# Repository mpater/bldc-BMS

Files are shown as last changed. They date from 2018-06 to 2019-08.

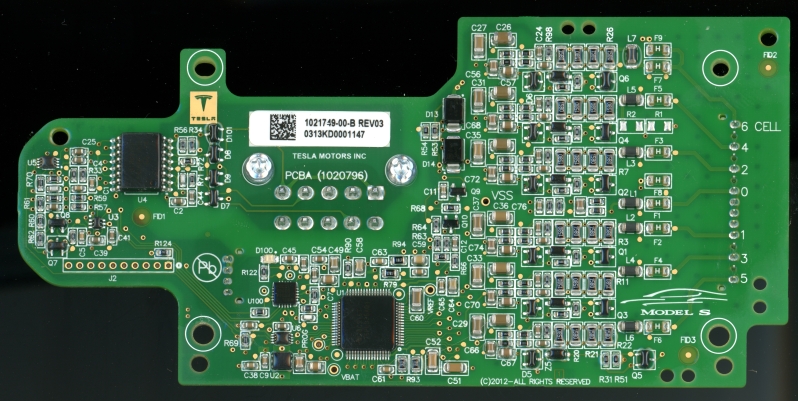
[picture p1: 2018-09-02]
datasheets/Telsa BMS.jpg

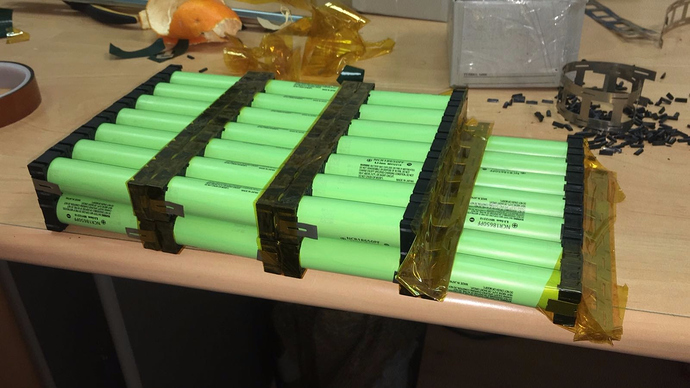
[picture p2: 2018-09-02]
datasheets/d7e37abb86a020a3c7433f02802cd9611f8715d7_1_690x388.jpg

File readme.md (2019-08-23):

# VESC BMS
## Overview
Battery Managment System (BMS) for (but not limited to) an Electronic Speed Controller, specifically for a longboard controller (VESC). 

Current battery pack specifications are LiFePO4 (3.2V nominal, ~2.6Ah) in a 6s2p, giving 19.2V with 5Ah (96Wh). Continuous discharge is about 20A (384W) with 30 second pulse discharge of 52A (1kW) and charge current of 5.2A (21.9V), for a 2p configuration.

Scope of the project is to design a BMS to meet the above specifications using off-the-shelf ICs for the battery managment section. A microcontroller circuit would also be incorperated to allow communication between the BMS and controller (SMBus/I2C), contrller and PC (USB-serial) and contrller and VESC (CAN bus).

Texis Instruments (TI) appears to have the most comprehensive set of battery managment systems offerings. These appear to be split up into two main sections: cell monitors and gas gauges. 
The bq769x0 seires will be used for the cell monitoring, offering bq76920, bq76930 and bq76940 based on the pack size. 
Currently the top candidats for the gas gauge are bq78350-R1 and bq34z100-R1 but more research is needed to determine which one is better suited. 

## BMS
- **Cell Monitor**
  - Measure cell voltages and pack current (Coulomb Counter)
  - Cell and temperature measurment
  - Charge Limit (over-voltage and over-amperage)
  - Discharge Limit (under-Voltage and over-amperage)
  - Balancing circuitry and autobalancing mode
  - 
- **'Gas Gauge' and Battery Managment Controller**
  - Estimate pack State of Charge (SoC)
  - Estimate pack State of Health (SoH)
  - Estimate time-to-empty
  - Lifetime datalogging
  - Aging compensation (optional)
  - Self-discharge compensation (optional)

### Cell Monitor
**bq76930**
- 6-19 cells, various chemistries
- 0x08 I2C Address (7-bit), 2.5V LDO, No CRC, 30-TSSOP (PW)
- PN bq7693000DBT

### Gas Gauge

#### bq78350-R1 - Gas Gauge via CEDV
See Technical Reference Sections:
- 9.1.11 - EDV Age Fator - Compensate for cell aging
- 9.1.12 - Self Discharge - estimate self-discharge

#### bq34z100-R1 - Gas Gauge via Impedance Track
'Impedance Track' module from TI give aging compensation and self-discharge compensation -> not true, bq78350 also has this. 
This module does not interface with cell monitor and reads only pack volage, how does it konw self-discharge issues?

## Microcontroller
The MCU provides a communiciton bridge between the gas gauge and PC (serial via USB) and gas gauge and VESC (CAN bus). The MCU does not need to be powered when either of these functions are not used, thus power to operate the MCU should come from either one of these communiciton ports. 
(or have MCU sleep when USB-serial timeout or CAN timeout? Wake-up via interrupt on button or USB-serial or CAN? Seems complicated.)

Firware updates done via SWD or Device firmware update via [USB DFU](http://www.st.com/content/ccc/resource/technical/document/application_note/6a/17/92/02/58/98/45/0c/CD00264379.pdf/files/CD00264379.pdf/jcr:content/translations/en.CD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).

STM32F072C8T6TR
CAN, HDMI-CEC, I²C (SMBus), IrDA, LIN, SPI, UART/USART, USB
IC MCU 32BIT 64KB FLASH 48LQFP
ARM® Cortex®-M0 STM32F0 Microcontroller IC 32-Bit 48MHz 64KB (64K x 8) FLASH 48-LQFP (7x7)

## Reference Projects
- TI Reference Design - TIDA-00449
- TI Reference Design - TIDA-00792
- TI Reference Disign - TIDA-00255
- LibreSolar
  - Also using bq769x0 for cell monitor but no gas gauge, that function is done by the MCU (STM32F072)

## TODO
- [x] Determine pack size and output - see intro
- [x] Determine cell monitor - bq76930
- [x] Determine gas gauge - bq78350-R1 or bq34z100-R1
- [x] Determine MCU - STM32F072 (USB-to-serial, USB bootloader, I2C, CAN)
- [x] 100% - Schematic capture
   - [x] Add pre-charge circuit
   - [x] Change balancing circuit from PNP to NPN
   - [x] Change power-stange layout to POS rail on top of sheet
   - [x] Setup for 6s? or have populated bypass for this layout
   - [x] Press button to show SoC LED display with gas-gauge?
   - [x] Jumper for MCU to be powered by pack
- [x] 100% - BoM and footprint selection for PCB
- [x] 1000% - Determine PCB footprint size constraights (multiple of 26650 cell size)
- [x] 100% - PCB capture
- [ ] 0% - write driver for gas gauge on MCU
- [ ] 0% - write interface module for MCU to PC
- [x] 100% - Order PCB and components
- [x] 100% - Assemble components on PCB
- [x] 100% - Hardware validation testing
- [ ] TI SMBus to PC moudule is very expensive, looking for something similar to view BMS status

## PCB_2019-06 TOFIX
- [ ] Swap I2C's on STM32F0 as I2C1 only support SMBus for bq78350-r1
- [ ] Mirror STM32F0 debug conn pinout
- [ ] Assemble and test PCB

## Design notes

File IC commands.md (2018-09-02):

## bq78350-R1
- ManufacturerAccess
- RemainingCapacityAlarm
- RemainingTimeAlarm
- BatteryMode
- BatteryMode
- AtRate
- AtRateTimeToFull
- AtRateTimeToEmpty
- AtRateOK
- Temperature
- Voltage
- Current
- AverageCurrent
- MaxError
- RelativeStateOfCharge
- AbsoluteStateOfCharge
- RemainingCapacity
- FullChargeCapacity
- RunTimeToEmpty
- AverageTimeToEmpty
- AverageTimeToFull
- ChargingCurrent
- ChargingVoltage
- BatteryStatus
- CycleCount
- DesignCapacity
- DesignVoltage
- SpecificationInfo
- ManufacturerDate
- SerialNumber
- ManufacturerName
- DeviceName
- DeviceChemistry
- ManufacturerData
- HostFETControl
- GPIOStatus
- GPIOControl
- VAUXVoltage
- Authenticate
- CellVoltage15 ... CellVoltage1
- DynamicPower
- ExtAveCellVoltage
- PendingEDV
- StateOfHealth
- SafetyAlert
- SafetyStatus
- PFAlert
- PFStatus
- OperationStatus
- ChargingStatus
- GaugingStatus
- ManufacturingStatus
- AFEStatus
- AFEConfig
- AFEVCx
- AFEData
- Lifetime Data Block 1 ... Lifetime Data Block 7
- ManufacturerInfo
- DAStatus 1
- DAStatus 2
- CUV Snapshot
- COV Snapshot

## bq34z100-G1
- Control()
- StateOfCharge()
- MaxError()
- RemainingCapacity()
- FullChargeCapacity()
- Voltage()
- AverageCurrent()
- Temperature()
- Flags()
- Current()
- FlagsB()

Extended Commands
- AverageTimeToEmpty()
- AverageTimeToFull()
- PassedCharge()
- DoD0Time()
- AvailableEnergy()
- AveragePower()
- Serial Number
- Internal_Temperature()
- CycleCount() - number of cycles the battery has
experienced
- StateOfHealth() - the ratio of predicted FCC (25°C, SOH current rate) over the DesignCapacity()
- ChargeVoltage() - recommended charging voltage output from the JEITA charging profile
- ChargeCurrent() - recommended charging current output from the JEITA charging profile
- PackConfiguration()
- DesignCapacity()
- DataFlashClass() (2)
- DataFlashBlock() (2)
- Authenticate()/BlockData()
- AuthenticateCheckSum()/BlockData()
- BlockData()
- BlockDataCheckSum()
- BlockDataControl()
- GridNumber()
- LearnedStatus()
- DoD@EoC() - depth of discharge (DOD) at the end of charge
- QStart() - initial capacity calculated from IT simulation
- TrueRC() - True remaining capacity from IT simulation
- TrueFCC() - True full charge capacity from IT simulation
- StateTime() - time past since last state change (DISCHARGE, CHARGE, REST)
- QMaxPassedQ
- DOD0()
- QmaxDOD0()
- QmaxTime()

## bq76930
- SYS_STAT
- CELLBAL1 CELLBAL2 - Enable individual cells for balancing
- SYS_CTRL1
- SYS_CTRL2 - Discharge and Charge FET control
- PROTECT1
- PROTECT2
- PROTECT3
- OV_TRIP
- UV_TRIP
- CC_CFG
- VC1_HI VC1_LO
- BAT_HI BAT_LO
- TS1_HI TS1_LO
- TS2_HI TS2_LO
- CC_HI CC_LO
- ADCGAIN1
- ADCOFFSET
- ADCGAIN2

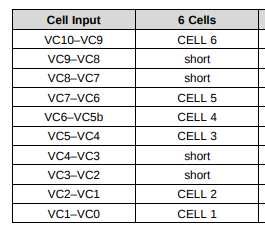
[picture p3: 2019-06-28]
datasheets/6-cell-config.png

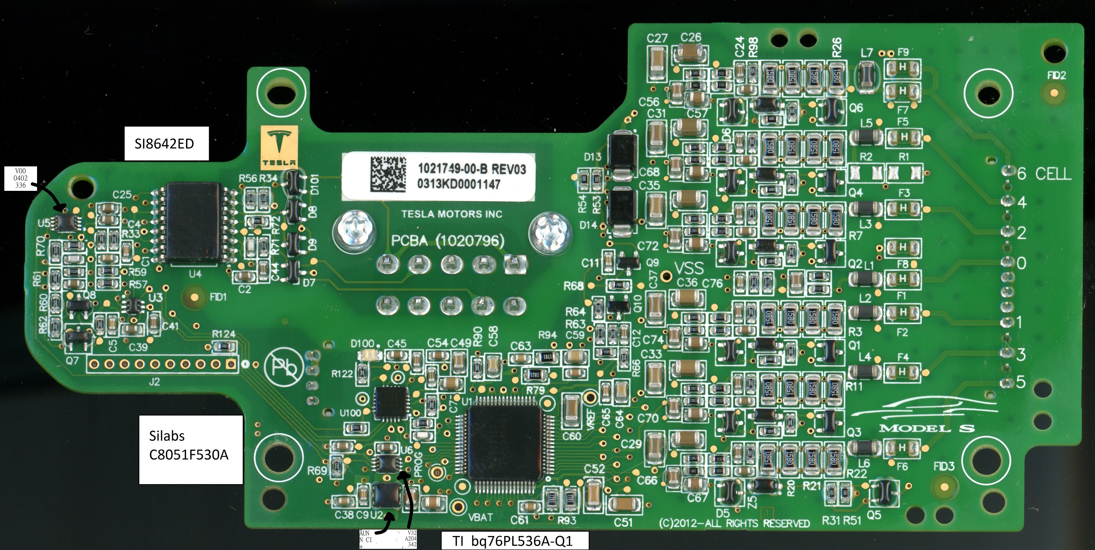
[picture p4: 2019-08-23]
datasheets/Telsa BMS large.jpg

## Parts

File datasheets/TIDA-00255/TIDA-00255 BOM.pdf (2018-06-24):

TI DESIGNS TIDA00255-bq76940

Item | Qty | Reference | Value | Part Description | Manufacturer | Manufacturer Part Number | Alternate Part | PCB Footprint | Note
1 | 6 | C1, C2, C3, C40, C41, C42 | 0.1uF | CAP, CERM, 0.1uF, 50V, +10/%, | MuRata | GCM188R71H104KA57B | | 0603 | -
2 | 4 | C4, C5, C6, C7 | 0.1uF | CAP, CERM, 0.1uF, 100V, +/-10%, X7R, 0603 | MuRata | GRM188R72A104KA35D | | 0603
3 | 21 | C8, C9, C10, C11, C12, C13, C14, C15, C16, C17, C18, C19, C21, C22, C23, C28, C29, C30, C31, C32, C33 | 1uF | CAP, CERM, 1uF, 16V, +10/%, X7R, 0805 | MuRata | GRM21BR71C105KA01L | | 0805
4 | 3 | C24, C25, C26 | 4700pF | CAP, CERM, 4700pF, 50V, +/-10%, X7R, 0805 | AVX | 08055C472KAT2A | | 0805
5 | 1 | C27 | 4.7uF | CAP, CERM, 4.7uF, 10V, +10/%, X7R, 0805 | MuRata | GRM21BR71A475KA73L | | 0805
6 | 3 | C34, C35, C36 | 10uF | CAP, CERM, 10uF, 35V, +/-10%, X7R, 1210 | MuRata | GRM32ER7YA106KA12L | | 1210
7 | 1 | C37 | 1uF | CAP, CERM, 1uF, 50V, +/-10%, X7R, 1206 | MuRata | GRM31MR71H105KA88L | | 1206
8 | 1 | C39 | 3300pF | CAP, CERM, 3300pF, 25V, +/-10%, X7R, 0603 | MuRata | GRM188R71E332KA01D | | 0603
9 | 1 | D1 | 75V | Diode, TVS, Uni, 75V, 1500W, SMC | Fairchild Semiconducto SMCJ75A | | | SMC
10 | 6 | D2, D22, D23, D24, D41, D46 100V | | Diode, Ultrafast, 100V, 0.15A, SOD-123 | Diodes Inc. | 1N4148W-7-F | | SOD-123
11 | 3 | D3, D45, D47 | 16V | Diode, Zener, 16V, 500mW, SOD-123 | Diodes Inc. | MMSZ5246B-7-F | | SOD-123
12 | 1 | D4 | 600V | Diode, Ultrafast, 600V, 3A, SMC | ON Semiconductor | MURS360T3G | | SMC
13 | 21 | D6, D7, D8, D9, D10, D11, D1 5.6V | | Diode, Zener, 5.6V, 200mW, SOD-323 | Diodes Inc. | MMSZ5232BS-7-F | | SOD-323
14 | 5 | D48, D49, D50, D51, D52 | Green | LED, Green, SMD | Lite-On | LTST-C190GKT | | 1.6x0.8x0.8mm
15 | 1 | D55 | Orange | LED, Orange, SMD | Lite-On | LTST-C190KFKT | | 1.6x0.8x0.8mm
16 | 1 | D56 | 6.8V | Diode, Zener, 6.8V, 500mW, SOD-123 | Diodes Inc. | MMSZ5235B-7-F | | SOD-123
17 | 3 | FID1, FID2, FID3 | | Fiducial mark. There is nothing to buy or mount. | N/A | N/A | | Fiducial
18 | 4 | H1, H2, H3, H4 | | Bumpon, Hemisphere, 0.375 X 0.235, Black | 3M | SJ61A2 | | Black Bumpon
19 | 4 | J1, J2, J3, J4 | | TERMINAL SCREW PC 30AMP, TH | Keystone | 8199 | | 12.9x6.3x7.9 mm
20 | 1 | J5 | | Header, 3.5mm, 11POS, R/A, TH | Molex | 395021011 | | 39.90x7.03x9.33 mm
21 | 4 | J6, J7, J11, J12 | | Header, 100mil, 2x1, Tin plated, TH Sullins Connector Solut PEC02SAAN | | | | Header, 2 PIN, 100mil, Tin
22 | 2 | J8, J17 | | Header, 100mil, 4x1, R/A, TH | Molex | 22-05-3041 | | 4x1 R/A Header
23 | 1 | J9 | | Header, 3.5mm, 5POS, R/A, TH | Molex | 395021005 | | 19.03x7.03x9.33 mm

# Bill of Materials

Item | Qty | Reference | Value | Part Description | Manufacturer | Manufacturer Part Number | Alternate Part | PCB Footprint | Note
24 | 1 | J14 | | Header, 100mil, 5x2, Tin plated, TH Sullins Connector Solut PEC05DAAN | | | | Header, 5x2, 100mil, Tin
25 | 1 | J15 | | Header, 100mil, 3x2, Tin, TH | Sullins Connector Solut PEC03DAAN | | | 3x2 Header
26 | 1 | J16 | | Header, 100mil, 3x1, Tin plated, TH Sullins Connector Solut PEC03SAAN | | | | Header, 3 PIN, 100mil, Tin
27 | 1 | LBL1 | | Thermal Transfer Printable Labels, | Brady | THT-14-423-10 | - | PCB Label 0.650"H x 0.200"W
28 | 1 | P1 | | CONN TERM BLOCK 3.5MM 11POS | Molex Connector Corpo39500-0011 | | 1840450 | Term Block Plug
29 | 1 | P2 | | CONN TERM BLOCK 3.5MM 5POS | Molex Connector Corpo39500-0005 | | - | Term Block Plug
30 | 2 | Q2, Q4 | 100V | MOSFET, N-CH, 100V, 18A, DDPAK | AOS | AOB290L | | DDPAK
31 | 2 | Q5, Q15 | -100V | MOSFET, P-CH, -100V, -0.6A, SOT- | Diodes Inc. | ZXMP10A13FTA | | SOT-23
32 | 8 | Q6, Q7, Q8, Q9, Q10, Q11, Q 20V | | MOSFET, P-CH, 20V, 0.83A, | Fairchild Semiconducto FDY1002PZ
33 | 2 | Q14, Q22 | 100V | MOSFET, N-CH, 100V, 0.19A, SOT- | NXP Semiconductor | BST82,215 | | SOT-23
34 | 2 | Q16, Q17 | 100V | MOSFET, N-CH, 100V, 0.17A, SOT- | Fairchild Semiconducto BSS123 | | | SOT-23
35 | 1 | Q18 | 0.5V | Transistor, PNP, 300V, 0.2A, SOT- | Fairchild Semiconducto MMBTA92 | | None | SOT-23
36 | 1 | Q19 | 50V | MOSFET, N-CH, 50V, 0.22A, SOT- | Fairchild Semiconducto BSS138 | | | SOT-23
37 | 1 | Q20 | 0.21V | Transistor, NPN, 20V, 5.25A, SOT- | Diodes Inc. | ZXTN19100CZTA | | SOT-89
38 | 18 | R2, R4, R44, R45, R46, R47, R 100 | | RES, 100 ohm, 1%, 0.125W, 0805 | Vishay-Dale | CRCW0805100RFKEA | | 0805
39 | 1 | R3 | 0.001 | RES, 0.001 ohm, 1%, 2W, 4527 | Vishay-Dale | WSR21L000FEA | | 4527
40 | 7 | R5, R8, R9, R104, R111, R116 1.00Meg | | RES, 1.00Meg ohm, 1%, 0.125W, | Vishay-Dale | CRCW08051M00FKEA | | 0805
41 | 2 | R6, R87 | 0 | RES, 0 ohm, 5%, 0.125W, 0805 | Vishay-Dale | CRCW08050000Z0EA | | 0805
42 | 22 | R7, R20, R21, R22, R23, R24, | 1.00k | RES, 1.00k ohm, 1%, 0.125W, 0805 | Vishay-Dale | CRCW08051K00FKEA | | 0805
43 | 15 | R10, R11, R12, R13, R14, R15 100 | | RES, 100 ohm, 1%, 0.25W, 1206 | Vishay-Dale | CRCW1206100RFKEA | | 1206
44 | 19 | R32, R33, R34, R35, R36, R37 10.0k | | RES, 10.0k ohm, 1%, 0.125W, 0805 | Vishay-Dale | CRCW080510K0FKEA | | 0805
45 | 1 | R42 | 499k | RES, 499k ohm, 1%, 0.125W, 0805 | Vishay-Dale | CRCW0805499KFKEA | | 0805
46 | 1 | R43 | 3.01k | RES, 3.01k ohm, 1%, 0.125W, 0805 | Vishay-Dale | CRCW08053K01FKEA | | 0805
47 | 6 | R75, R78, R101, R103, R107, | 100k | RES, 100k ohm, 1%, 0.125W, 0805 | Vishay-Dale | CRCW0805100KFKEA | | 0805
48 | 16 | R76, R124, R125, R126, R127 200 | | RES, 200 ohm, 1%, 0.125W, 0805 | Vishay-Dale | CRCW0805200RFKEA | | 0805
49 | 1 | R85 | 0 | RES, 0 ohm, 5%, 0.25W, 1206 | Vishay-Dale | CRCW12060000Z0EA | | 1206
50 | 1 | R94 | 300k | RES, 300k ohm, 0.1%, 0.1W, 0603 | Susumu Co Ltd | RG1608P-304-B-T5 | | 0603
51 | 2 | R95, R97 | 100k | RES, 100k ohm, 0.1%, 0.1W, 0603 | Susumu Co Ltd | RG1608P-104-B-T5 | | 0603
52 | 2 | R96, R102 | 7.68k | RES, 7.68k ohm, 0.1%, 0.1W, 0603 | Susumu Co Ltd | RG1608P-7681-B-T5 | | 0603
53 | 1 | R105 | 5.6k | RES, 5.6k ohm, 5%, 1W, 2512 | Panasonic | ERJ-1TYJ562U | | 2512
54 | 1 | R106 | 196k | RES, 196k ohm, 1%, 0.125W, 0805 | Vishay-Dale | CRCW0805196KFKEA | | 0805
55 | 2 | R110, R122 | 49.9k | RES, 49.9k ohm, 1%, 0.125W, 0805 | Vishay-Dale | CRCW080549K9FKEA | | 0805
56 | 1 | R120 | 221k | RES, 221k ohm, 1%, 0.125W, 0805 | Vishay-Dale | CRCW0805221KFKEA | | 0805
57 | 1 | R121 | 698 | RES, 698 ohm, 1%, 0.125W, 0805 | Vishay-Dale | CRCW0805698RFKEA | | 0805
58 | 3 | RT1, RT2, RT3 | 10.0k ohm | Thermistor NTC, 10.0k ohm, 1%, | SEMITEC Corporation | 103AT-2 | | Disc, 5x8.4 mm
59 | 2 | S1, S2 | | Switch, Tactile, SPST-NO, 0.05A, | TE Connectivity | 4-1437565-1 | | SW, SPST 6x6 mm
60 | 1 | S3 | | Switch, SPST 9Pos, Rocker, TH | Grayhill | 76SB09ST | | 9.65X8X24.9mm
61 | 1 | S4 | | Switch, SPST 8Pos, Rocker, TH | Grayhill | 76SB08ST | | 9.65X8X22.4mm
62 | 10 | SH-J6, SH-J7, SH-J11, SH-J12, 1x2 | | Shunt, 100mil, Gold plated, Black | 3M | 969102-0000-DA | SNT-100-BK-G | Shunt
63 | 4 | TP3, TP4, TP5, TP6 | Black | Test Point, TH, Multipurpose, Black Keystone | | 5011 | | Keystone5011
64 | 3 | TP48, TP49, TP50 | Yellow | Test Point, Multipurpose, Yellow, | Keystone | 5014 | | Yellow Multipurpose Testpoint
65 | 1 | U1 | | bq76940 AFE for 15-Series Cell | Texas Instruments | BQ7694000DBT | | DBT0044A
66 | 1 | U2 | | Companion Controller for bq769x0 | Texas Instruments | BQ78350DBT | | DBT0030A
67 | 0 | C20 | 470pF | CAP, CERM, 470pF, 50V, +/-10%, | AVX | 08055C471KAT2A | | 0805
68 | 0 | C38 | 3300pF | CAP, CERM, 3300pF, 25V, +/-10%, | MuRata | GRM188R71E332KA01D | | 0603
69 | 0 | D5 | 600V | Diode, Ultrafast, 600V, 8A, TH | ON Semiconductor | MUR860G | | TO-220AC
70 | 0 | D16, D17, D18, D19, D20, D2 0.8V | | Diode, Schottky, 30V, 0.2A, SOD- | ON Semiconductor | BAT54T1G | | SOD-123
71 | 0 | D37 | | Diode, Schottky, 30V, 0.2A, SOD- | ON Semiconductor | BAT54T1G | | SOD-123
72 | 0 | D38, D39, D40, D42 | | Diode, TVS, Uni, 30V, 600W, SMB | Diodes Inc. | SMBJ30A-13-F | | SMB
73 | 0 | HS1, HS2, HS3, HS4 | | Heatsink, DDPAK/TO-263, SMT | Aavid | 573300D00010G | | Heatsink, DDPAk

Item | Qty | Reference | Value | Part Description | Manufacturer | Manufacturer Part Number | Alternate Part | PCB Footprint | Note
74 | 0 | J10 | | Header, TH, 100mil, 3x1, Gold | Samtec, Inc. | TSW-103-07-G-S | | TSW-103-07-G-S
75 | 0 | J13 | | Header, TH, 100mil, 7x1, Gold | Samtec | TSW-107-07-G-S | | 7x1 Header
76 | 0 | J18, J19 | | Header, TH, 100mil, 5x1, Gold | Samtec, Inc. | TSW-105-07-G-S | | TSW-105-07-G-S
77 | 0 | J20 | | Header, TH, 100mil, 6x1, Gold | Samtec, Inc. | TSW-106-07-G-S | | TSW-106-07-G-S
78 | 0 | Q1, Q3 | 100V | MOSFET, N-CH, 100V, 18A, DDPAK | AOS | AOB290L | | DDPAK
79 | 0 | Q21 | 0.7V | Transistor, NPN, 65V, 0.1A, SOT-23 | ON Semiconductor | BC846BLT1G | None | SOT-23
80 | 0 | R1, R50, R51, R123 | 0 | RES, 0 ohm, 5%, 0.125W, 0805 | Vishay-Dale | CRCW08050000Z0EA | | 0805
81 | 0 | R74 | 100k | RES, 100k ohm, 1%, 0.125W, 0805 | Vishay-Dale | CRCW0805100KFKEA | | 0805
82 | 0 | R77 | 200 | RES, 200 ohm, 1%, 0.125W, 0805 | Vishay-Dale | CRCW0805200RFKEA | | 0805
83 | 0 | R80, R81, R98, R99, R113 | 1.00k | RES, 1.00k ohm, 1%, 0.125W, 0805 | Vishay-Dale | CRCW08051K00FKEA | | 0805
84 | 0 | R84 | 300k | RES, 300k ohm, 0.1%, 0.1W, 0603 | Susumu Co Ltd | RG1608P-304-B-T5 | | 0603
85 | 0 | R86 | 0 | RES, 0 ohm, 5%, 0.25W, 1206 | Vishay-Dale | CRCW12060000Z0EA | | 1206
86 | 0 | R88, R93 | 100k | RES, 100k ohm, 0.1%, 0.1W, 0603 | Susumu Co Ltd | RG1608P-104-B-T5 | | 0603
87 | 0 | R91, R92, R100 | 1.00Meg | RES, 1.00Meg ohm, 1%, 0.125W, | Vishay-Dale | CRCW08051M00FKEA | | 0805
88 | 0 | TP1 | Black | Test Point, TH, Multipurpose, Black Keystone | | 5011 | | Keystone5011
89 | 0 | TP2, TP14 | Red | Test Point, TH, Multipurpose, Red | Keystone | 5010 | | Keystone5010
90 | 0 | TP7, TP8, TP10, TP11, TP13, T White | | Test Point, TH, Multipurpose, | Keystone | 5012 | | Keystone5012

IMPORTANT NOTICE FOR TI REFERENCE DESIGNS Texas Instruments Incorporated ("TI") reference designs are solely intended to assist designers (“Buyers”) who are developing systems that incorporate TI semiconductor products (also referred to herein as “components”). Buyer understands and agrees that Buyer remains responsible for using its independent analysis, evaluation and judgment in designing Buyer’s systems and products.
TI reference designs have been created using standard laboratory conditions and engineering practices. TI has not conducted any
testing other than that specifically described in the published documentation for a particular reference design. TI may make
corrections, enhancements, improvements and other changes to its reference designs.
Buyers are authorized to use TI reference designs with the TI component(s) identified in each particular reference design and to modify the reference design in the development of their end products. HOWEVER, NO OTHER LICENSE, EXPRESS OR IMPLIED, BY ESTOPPEL OR OTHERWISE TO ANY OTHER TI INTELLECTUAL PROPERTY RIGHT, AND NO LICENSE TO ANY THIRD PARTY TECHNOLOGY OR INTELLECTUAL PROPERTY RIGHT, IS GRANTED HEREIN, including but not limited to any patent right, copyright, mask work right, or other intellectual property right relating to any combination, machine, or process in which TI components or services are used. Information published by TI regarding third-party products or services does not constitute a license to use such products or services, or a warranty or endorsement thereof. Use of such information may require a license from a third party under the patents or other intellectual property of the third party, or a license from TI under the patents or other intellectual property of TI.
TI REFERENCE DESIGNS ARE PROVIDED "AS IS". TI MAKES NO WARRANTIES OR REPRESENTATIONS WITH REGARD TO THE REFERENCE DESIGNS OR USE OF THE REFERENCE DESIGNS, EXPRESS, IMPLIED OR STATUTORY, INCLUDING ACCURACY OR COMPLETENESS. TI DISCLAIMS ANY WARRANTY OF TITLE AND ANY IMPLIED WARRANTIES OF MERCHANTABILITY, FITNESS FOR A PARTICULAR PURPOSE, QUIET ENJOYMENT, QUIET POSSESSION, AND NON-INFRINGEMENT OF ANY THIRD PARTY INTELLECTUAL PROPERTY RIGHTS WITH REGARD TO TI REFERENCE DESIGNS OR USE THEREOF. TI SHALL NOT BE LIABLE FOR AND SHALL NOT DEFEND OR INDEMNIFY BUYERS AGAINST ANY THIRD PARTY INFRINGEMENT CLAIM THAT RELATES TO OR IS BASED ON A COMBINATION OF COMPONENTS PROVIDED IN A TI REFERENCE DESIGN. IN NO EVENT SHALL TI BE LIABLE FOR ANY ACTUAL, SPECIAL, INCIDENTAL, CONSEQUENTIAL OR INDIRECT DAMAGES, HOWEVER CAUSED, ON ANY THEORY OF LIABILITY AND WHETHER OR NOT TI HAS BEEN ADVISED OF THE POSSIBILITY OF SUCH DAMAGES, ARISING IN ANY WAY OUT OF TI REFERENCE DESIGNS OR BUYER’S USE OF TI REFERENCE DESIGNS.
TI reserves the right to make corrections, enhancements, improvements and other changes to its semiconductor products and services per JESD46, latest issue, and to discontinue any product or service per JESD48, latest issue. Buyers should obtain the latest relevant information before placing orders and should verify that such information is current and complete. All semiconductor products are sold subject to TI’s terms and conditions of sale supplied at the time of order acknowledgment.
TI warrants performance of its components to the specifications applicable at the time of sale, in accordance with the warranty in TI’s terms and conditions of sale of semiconductor products. Testing and other quality control techniques for TI components are used to the extent TI deems necessary to support this warranty. Except where mandated by applicable law, testing of all parameters of each component is not necessarily performed.
TI assumes no liability for applications assistance or the design of Buyers’ products. Buyers are responsible for their products and applications using TI components. To minimize the risks associated with Buyers’ products and applications, Buyers should provide adequate design and operating safeguards.
Reproduction of significant portions of TI information in TI data books, data sheets or reference designs is permissible only if reproduction is without alteration and is accompanied by all associated warranties, conditions, limitations, and notices. TI is not responsible or liable for such altered documentation. Information of third parties may be subject to additional restrictions.
Buyer acknowledges and agrees that it is solely responsible for compliance with all legal, regulatory and safety-related requirements concerning its products, and any use of TI components in its applications, notwithstanding any applications-related information or support that may be provided by TI. Buyer represents and agrees that it has all the necessary expertise to create and implement safeguards that anticipate dangerous failures, monitor failures and their consequences, lessen the likelihood of dangerous failures and take appropriate remedial actions. Buyer will fully indemnify TI and its representatives against any damages arising out of the use of any TI components in Buyer’s safety-critical applications.
In some cases, TI components may be promoted specifically to facilitate safety-related applications. With such components, TI’s goal is to help enable customers to design and create their own end-product solutions that meet applicable functional safety standards and requirements. Nonetheless, such components are subject to these terms.
No TI components are authorized for use in FDA Class III (or similar life-critical medical equipment) unless authorized officers of the parties have executed an agreement specifically governing such use.
Only those TI components that TI has specifically designated as military grade or “enhanced plastic” are designed and intended for use in military/aerospace applications or environments. Buyer acknowledges and agrees that any military or aerospace use of TI components that have not been so designated is solely at Buyer's risk, and Buyer is solely responsible for compliance with all legal and regulatory requirements in connection with such use.
TI has specifically designated certain components as meeting ISO/TS16949 requirements, mainly for automotive use. In any case of use of non-designated products, TI will not be responsible for any failure to meet ISO/TS16949.

Mailing Address: Texas Instruments, Post Office Box 655303, Dallas, Texas 75265 Copyright © 2014, Texas Instruments Incorporated

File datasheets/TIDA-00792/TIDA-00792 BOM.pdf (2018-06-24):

Filename: ProF7BE.tmp | TIDA-00792
Variant: | 001 | E2
Generated: 3/15/2017 12:29:49 PM
TID #: | TIDA-00792 | TIDA-00792 REV E2 Bill of Materials
Item # | Designator | Quantity | Value | PartNumber | Manufacturer | Description | PackageReference
1 | !PCB1 | 1 | | TIDA-00792 | Any | Printed Circuit Board
2 | C1, C5 | 2 | 0.01uF | 08051C103KAT2A | AVX | CAP, CERM, 0.01uF, 100V, +/-10%, X7R, 0805 | 0805
3 | C2 | 1 | 1.5uF | GRM21BR71E155KA88L | MuRata | CAP, CERM, 1.5 µF, 25 V, +/- 10%, X7R, 0805 | 0805
4 | C3, C4, C6, C7 | 4 | 0.1uF | GRM188R72A104KA35D | MuRata | CAP, CERM, 0.1uF, 100V, +/-10%, X7R, 0603 | 0603
5 | C8, C9, C10, C11, C12, C13, C14, C15, C16, C17, C18, C19, C20, C21, C22, C23, C24, C25, C43 | 19 | 0.22uF | 885012206048 | Wurth Elektronik | CAP, CERM, 0.22 µF, 16 V, +/- 10%, X7R, 0603 | 0603
6 | C26, C36 | 2 | 470pF | 885012206081 | Wurth Elektronik | CAP, CERM, 470 pF, 50 V, +/- 10%, X7R, 0603 | 0603
7 | C27, C28, C29, C46, C47 | 5 | 0.1uF | C1608X7R1H104K080AA | TDK | CAP, CERM, 0.1 µF, 50 V, +/- 10%, X7R, 0603 | 0603
8 | C30, C31, C32 | 3 | 4700pF | 885012206087 | Wurth Elektronik | CAP, CERM, 4700 pF, 50 V, +/- 10%, X7R, 0603 | 0603
9 | C33, C34, C35 | 3 | 1uF | 885012206052 | Wurth Elektronik | CAP, CERM, 1 µF, 16 V, +/- 10%, X7R, 0603 | 0603
10 | C37, C38, C39 | 3 | 10uF | GRM32ER7YA106KA12L | MuRata | CAP, CERM, 10 µF, 35 V, +/- 10%, X7R, 1210 | 1210
11 | C40 | 1 | 4.7uF | 885012207025 | Wurth Elektronik | CAP, CERM, 4.7 µF, 10 V, +/- 10%, X7R, 0805 | 0805
12 | C41, C42 | 2 | 1uF | GRM21BR71H105KA12L | MuRata | CAP, CERM, 1 µF, 50 V, +/- 10%, X7R, 0805 | 0805
13 | C44, C45 | 2 | 3300pF | GRM188R71E332KA01D | MuRata | CAP, CERM, 3300pF, 25V, +/-10%, X7R, 0603 | 0603
14 | D1, D5 | 2 | 60V | SMCJ60A | Fairchild Semiconductor | Diode, TVS, Uni, 60 V, 1500 W, SMC | SMC
15 | D2, D3 | 2 | 16V | MMSZ5246BS-7-F | Diodes Inc. | Diode, Zener, 16 V, 200 mW, SOD-323 | SOD-323
16 | D4, D28, D30 | 3 | 18V | MMSZ5248BS-7-F | Diodes Inc. | Diode, Zener, 18 V, 200 mW, SOD-323 | SOD-323
17 | D6 | 1 | 200V | ES3D-E3/57T | Vishay-Semiconductor | Diode, Ultrafast, 200V, 3A, SMC | SMC
18 | D7, D8, D9, D10, D11, D12, D13, D14, D15, D16, D17, D18, D19, D20, D21 | 15 | 5.6V | MMSZ5232BS-7-F | Diodes Inc. | Diode, Zener, 5.6V, 200mW, SOD-323 | SOD-323
19 | D22, D23, D24, D25, D27 | 5 | 100V | 1N4148W-7-F | Diodes Inc. | Diode, Ultrafast, 100V, 0.15A, SOD-123 | SOD-123
20 | D26 | 1 | 3.9V | MMSZ5228BS-7-F | Diodes Inc. | Diode, Zener, 3.9 V, 200 mW, SOD-323 | SOD-323
21 | D31, D32, D33, D34, D35 | 5 | Green | LTST-C190GKT | Lite-On | LED, Green, SMD | 1.6x0.8x0.8mm
22 | H1, H2, H3, H4 | 4 | | 573300D00010G | Aavid | Heatsink, DDPAK/TO-263, SMT | Heatsink, DDPAk
23 | H5, H7, H9, H11 | 4 | | 1902C | Keystone | Standoff, Hex, 0.5"L #4-40 Nylon | Standoff
24 | H6, H8, H10, H12 | 4 | | NY PMS 440 0025 PH | B&F Fastener Supply | Machine Screw, Round, #4-40 x 1/4, Nylon, Philips panhead | Screw
25 | J5 | 1 | | 395021005 | Molex | Header (shrouded), 3.5mm, 5x1, R/A, TH | 19.03x7.03x9.33 mm
26 | J6 | 1 | | 395021011 | Molex | Terminal block, 3.5mm, 11x1, R/A, TH | 39.90x7.03x9.33 mm
27 | J7, J8 | 2 | | 22-05-3041 | Molex | Header (friction lock), 100mil, 4x1, R/A, TH | 4x1 R/A Header
28 | L1, L2, L3, L4 | 4 | 220 ohm | BLM18SG221TN1D | MuRata | Ferrite Bead, 220 ohm @ 100 MHz, 2.5 A, 0603 | 0603
29 | LBL1 | 1 | | THT-14-423-10 | Brady | Thermal Transfer Printable Labels, 0.650" W x 0.200" H - 10,000 per roll | PCB Label 0.650"H x 0.200"W
30 | Q1, Q2, Q4, Q5 | 4 | 100V | CSD19536KTT | Texas Instruments | MOSFET, N-CH, 100 V, 200 A, KTT0002A | KTT0002A
31 | Q3, Q23, Q26 | 3 | -100V | ZXMP10A13FTA | Diodes Inc. | MOSFET, P-CH, -100V, -0.6A, SOT-23 | SOT-23
32 | Q6, Q7, Q8, Q9, Q10, Q11, Q12, Q13, Q14, Q15, Q16, Q17, Q18, Q19, Q20 | 15 | 12V | CSD13381F4 | Texas Instruments | MOSFET, N/P-CH, 12 V, 2.1 A, 1.0x0.35x0.6mm | 1.0x0.35x0.6mm
33 | Q21 | 1 | 100V | BST82,215 | NXP Semiconductor | MOSFET, N-CH, 100 V, 0.19 A, SOT-23 | SOT-23
34 | Q22, Q25, Q27 | 3 | 100V | BSS123 | Fairchild Semiconductor | MOSFET, N-CH, 100V, 0.17A, SOT-23 | SOT-23
35 | Q24 | 1 | 100 V | ZXTN19100CZTA | Diodes Inc. | Transistor, NPN, 100 V, 5.25 A, SOT-89 | SOT-89
36 | R3, R18 | 2 | 100 | CRCW0603100RFKEA | Vishay-Dale | RES, 100 ohm, 1%, 0.1W, 0603 | 0603
37 | R4 | 1 | 0.001 | CSNL2010FT1L00 | Stackpole Electronics Inc | RES, 0.001, 1%, 1.5 W, 2010 | 2010
38 | R6, R11, R16 | 3 | 10.0Meg | CRCW060310M0FKEA | Vishay-Dale | RES, 10.0Meg ohm, 1%, 0.1W, 0603 | 0603
39 | R7, R8, R9, R10 | 4 | 1.2k | CRCW25121K20JNEG | Vishay-Dale | RES, 1.2 k, 5%, 1 W, AEC-Q200 Grade 0, 2512 | 2512
40 | R12, R13, R14 | 3 | 620 | CRCW0603620RJNEA | Vishay-Dale | RES, 620, 5%, 0.1 W, 0603 | 0603
41 | R15, R97, R98 | 3 | 100 | CRCW0603100RJNEA | Vishay-Dale | RES, 100, 5%, 0.1 W, 0603 | 0603
42 | R17, R96 | 2 | 0 | CRCW06030000Z0EA | Vishay-Dale | RES, 0, 5%, 0.1 W, 0603 | 0603
43 | R19, R20, R21, R22, R23, R24, R25, R26, R27, R28, R29, R30, R31, R32, R33 | 15 | 28.7 | CRCW201028R7FKEF | Vishay-Dale | RES, 28.7, 1%, 0.75 W, 2010 | 2010
44 | R34, R35, R37, R39, R41, R43, R45, R46, R47, R49, R51, R53, R55, R57, R58, R59, R61, R63, R65, R67, R69, R91 | 22 | 1.0k | CRCW06031K00JNEA | Vishay-Dale | RES, 1.0 k, 5%, 0.1 W, 0603 | 0603
45 | R36, R38, R40, R42, R44, R48, R50, R52, R54, R56, R60, R62, R64, R66, R68, R78, R82 | 17 | 10k | CRCW060310K0JNEA | Vishay-Dale | RES, 10 k, 5%, 0.1 W, 0603 | 0603
46 | R73 | 1 | 499k | CRCW0603499KFKEA | Vishay-Dale | RES, 499 k, 1%, 0.1 W, 0603 | 0603
47 | R74, R75 | 2 | 100 | CRCW0805100RFKEA | Vishay-Dale | RES, 100 ohm, 1%, 0.125W, 0805 | 0805
48 | R76, R77, R85 | 3 | 100k | CRCW0805100KFKEA | Vishay-Dale | RES, 100k ohm, 1%, 0.125W, 0805 | 0805
49 | R79, R84 | 2 | 10.0Meg | CRCW060310M0FKEA | Vishay-Dale | RES, 10.0 M, 1%, 0.1 W, 0603 | 0603
50 | R80 | 1 | 51k | CRCW060351K0JNEA | Vishay-Dale | RES, 51 k, 5%, 0.1 W, 0603 | 0603
51 | R81 | 1 | 1.0k | CRCW20101K00JNEF | Vishay-Dale | RES, 1.0 k, 5%, 0.75 W, AEC-Q200 Grade 0, 2010 | 2010
52 | R87 | 1 | 1.0Meg | CRCW06031M00JNEA | Vishay-Dale | RES, 1.0 M, 5%, 0.1 W, 0603 | 0603
53 | R88 | 1 | 750 | CRCW2010750RJNEF | Vishay-Dale | RES, 750, 5%, 0.75 W, 2010 | 2010
54 | R89, R92, R100, R101 | 4 | 300k | RG1608P-304-B-T5 | Susumu Co Ltd | RES, 300k ohm, 0.1%, 0.1W, 0603 | 0603
55 | R94, R103 | 2 | 100k | CRCW0603100KJNEA | Vishay-Dale | RES, 100 k, 5%, 0.1 W, 0603 | 0603
56 | R99, R102 | 2 | 10.0k | RG1608P-103-B-T5 | Susumu Co Ltd | RES, 10.0 k, 0.1%, 0.1 W, 0603 | 0603
57 | R104, R108 | 2 | 220k | CRCW0603220KJNEA | Vishay-Dale | RES, 220 k, 5%, 0.1 W, 0603 | 0603
58 | R105, R106 | 2 | 510k | CRCW0603510KJNEA | Vishay-Dale | RES, 510 k, 5%, 0.1 W, 0603 | 0603
59 | R107 | 1 | 113k | CRCW0603113KFKEA | Vishay-Dale | RES, 113 k, 1%, 0.1 W, 0603 | 0603
60 | RT1, RT2, RT3 | 3 | 10.0k ohm | 103AT-2 | SEMITEC Corporation | Thermistor NTC, 10.0k ohm, 1%, Disc, 5x8.4 mm | Disc, 5x8.4 mm
61 | S1 | 1 | | 4-1437565-1 | TE Connectivity | Switch, Tactile, SPST-NO, 0.05A, 12V, SMT | SW, SPST 6x6 mm
62 | TP19, TP20, TP21, TP30 | 4 | | 5011 | Keystone | Test Point, Multipurpose, Black, TH | Black Multipurpose Testpoint
63 | U1 | 1 | | BQ76200PWR | Texas Instruments | bq76200: Low-Power, High-Side N-channel FET Driver with Pack Voltage Monitor, PW0016A | PW0016A
64 | U2 | 1 | | BQ7694000DBTR | Texas Instruments | Battery Monitor for Lithium-Ion and Phosphate Battery Packs, DBT0044A | DBT0044A
65 | U3, U4, U5 | 3 | | TPD1E10B06DPYT | Texas Instruments | ESD Protection in 0402 Package with 10 pF Capacitance and 6 V Breakdown, 1 Channel, -40 to +125 degC, 2-pin X2SON (DPY) | DPY0002A
66 | U7 | 1 | | BQ78350DBTR-R1 | Texas Instruments | CEDV Li-Ion Gas Gauge and Battery Management Controller Companion to the bq769x0 Battery Monitoring AFE, DBT0030A | DBT0030A
67 | D29 | 0 | 3.9V | MMSZ5228BS-7-F | Diodes Inc. | Diode, Zener, 3.9 V, 200 mW, SOD-323 | SOD-323
68 | FID1, FID2, FID3 | 0 | | N/A | N/A | Fiducial mark. There is nothing to buy or mount. | Fiducial
69 | J1, J2, J3, J4 | 0 | | L35 | Thomas & Betts | Connector, L Type Copper Single Conductor, TH | Connector, L Type Copper Single Conductor, TH
70 | R1, R2, R70, R71, R72, R93 | 0 | 0 | CRCW06030000Z0EA | Vishay-Dale | RES, 0, 5%, 0.1 W, 0603 | 0603
71 | R5 | 0 | 0.001 | CSNL2010FT1L00 | Stackpole Electronics Inc | RES, 0.001, 1%, 1.5 W, 2010 | 2010
72 | R83, R86, R90 | 0 | 1.0k | CRCW06031K00JNEA | Vishay-Dale | RES, 1.0 k, 5%, 0.1 W, 0603 | 0603
73 | R95 | 0 | 1.0Meg | CRCW06031M00JNEA | Vishay-Dale | RES, 1.0 M, 5%, 0.1 W, 0603 | 0603
74 | TP14, TP15 | 0 | | PEC03SAAN | Sullins Connector Solutions | Header, 100mil, 3x1, Tin, TH | Header, 3 PIN, 100mil, Tin
75 | TP16 | 0 | | PEC02SAAN | Sullins Connector Solutions | Header, 100mil, 2x1, Tin, TH | Header, 2 PIN, 100mil, Tin
76 | U6 | 0 | | TPD1E10B06DPYT | Texas Instruments | ESD Protection in 0402 Package with 10 pF Capacitance and 6 V Breakdown, 1 Channel, -40 to +125 degC, 2-pin X2SON (DPY) | DPY0002A

# IMPORTANT NOTICE FOR TI DESIGN INFORMATION AND RESOURCES

Texas Instruments Incorporated (‘TI”) technical, application or other design advice, services or information, including, but not limited to, reference designs and materials relating to evaluation modules, (collectively, “TI Resources”) are intended to assist designers who are developing applications that incorporate TI products; by downloading, accessing or using any particular TI Resource in any way, you (individually or, if you are acting on behalf of a company, your company) agree to use it solely for this purpose and subject to the terms of this Notice.
TI’s provision of TI Resources does not expand or otherwise alter TI’s applicable published warranties or warranty disclaimers for TI products, and no additional obligations or liabilities arise from TI providing such TI Resources. TI reserves the right to make corrections, enhancements, improvements and other changes to its TI Resources.
You understand and agree that you remain responsible for using your independent analysis, evaluation and judgment in designing your applications and that you have full and exclusive responsibility to assure the safety of your applications and compliance of your applications (and of all TI products used in or for your applications) with all applicable regulations, laws and other applicable requirements. You represent that, with respect to your applications, you have all the necessary expertise to create and implement safeguards that (1) anticipate dangerous consequences of failures, (2) monitor failures and their consequences, and (3) lessen the likelihood of failures that might cause harm and take appropriate actions. You agree that prior to using or distributing any applications that include TI products, you will thoroughly test such applications and the functionality of such TI products as used in such applications. TI has not conducted any testing other than that specifically described in the published documentation for a particular TI Resource.
You are authorized to use, copy and modify any individual TI Resource only in connection with the development of applications that include the TI product(s) identified in such TI Resource. NO OTHER LICENSE, EXPRESS OR IMPLIED, BY ESTOPPEL OR OTHERWISE TO ANY OTHER TI INTELLECTUAL PROPERTY RIGHT, AND NO LICENSE TO ANY TECHNOLOGY OR INTELLECTUAL PROPERTY RIGHT OF TI OR ANY THIRD PARTY IS GRANTED HEREIN, including but not limited to any patent right, copyright, mask work right, or other intellectual property right relating to any combination, machine, or process in which TI products or services are used. Information regarding or referencing third-party products or services does not constitute a license to use such products or services, or a warranty or endorsement thereof. Use of TI Resources may require a license from a third party under the patents or other intellectual property of the third party, or a license from TI under the patents or other intellectual property of TI.
TI RESOURCES ARE PROVIDED “AS IS” AND WITH ALL FAULTS. TI DISCLAIMS ALL OTHER WARRANTIES OR REPRESENTATIONS, EXPRESS OR IMPLIED, REGARDING TI RESOURCES OR USE THEREOF, INCLUDING BUT NOT LIMITED TO ACCURACY OR COMPLETENESS, TITLE, ANY EPIDEMIC FAILURE WARRANTY AND ANY IMPLIED WARRANTIES OF MERCHANTABILITY, FITNESS FOR A PARTICULAR PURPOSE, AND NON-INFRINGEMENT OF ANY THIRD PARTY INTELLECTUAL PROPERTY RIGHTS.
TI SHALL NOT BE LIABLE FOR AND SHALL NOT DEFEND OR INDEMNIFY YOU AGAINST ANY CLAIM, INCLUDING BUT NOT LIMITED TO ANY INFRINGEMENT CLAIM THAT RELATES TO OR IS BASED ON ANY COMBINATION OF PRODUCTS EVEN IF DESCRIBED IN TI RESOURCES OR OTHERWISE. IN NO EVENT SHALL TI BE LIABLE FOR ANY ACTUAL, DIRECT, SPECIAL, COLLATERAL, INDIRECT, PUNITIVE, INCIDENTAL, CONSEQUENTIAL OR EXEMPLARY DAMAGES IN CONNECTION WITH OR ARISING OUT OF TI RESOURCES OR USE THEREOF, AND REGARDLESS OF WHETHER TI HAS BEEN ADVISED OF THE POSSIBILITY OF SUCH DAMAGES.
You agree to fully indemnify TI and its representatives against any damages, costs, losses, and/or liabilities arising out of your non-compliance with the terms and provisions of this Notice.
This Notice applies to TI Resources. Additional terms apply to the use and purchase of certain types of materials, TI products and services. These include; without limitation, TI’s standard terms for semiconductor products http://www.ti.com/sc/docs/stdterms.htm), evaluation modules, (http://www.ti.com/lit/pdf/SSZZ027) and samples (http://www.ti.com/sc/docs/sampterms.htm).

# Mailing Address: Texas Instruments, Post Office Box 655303, Dallas, Texas 75265 Copyright © 2017, Texas Instruments Incorporated

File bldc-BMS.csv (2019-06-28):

Reference | Quantity | Value | Footprint | Datasheet | Description | Digikey PN
C11 | 1 | 470nF | Capacitor_SMD:C_0603_1608Metric | ~ | CAP CER 0.47UF 25V X7R 0603 | 1276-2082-1-ND
C12 C16 | 2 | 15pF | Capacitor_SMD:C_0603_1608Metric | ~ | CAP CER 15PF 50V C0G/NP0 0603 | 1292-1487-1-ND
C2 C10 C13 C14 C15 C18 C19 C21 C20 C23 C22 C27 | 12 | 1uF 10V | Capacitor_SMD:C_0603_1608Metric |  | CAP CER 1UF 25V X5R 0603 | 1276-1102-1-ND
C24 | 1 | 4.7uF | Capacitor_SMD:C_0805_2012Metric |  | CAP CER 4.7UF 25V X5R 0805 | 1276-1244-1-ND
C25 C26 | 2 | 4.7nF | Capacitor_SMD:C_0603_1608Metric |  | CAP CER 4700PF 50V C0G 0603 | 445-7400-1-ND
C29 | 1 | 3.3uF | Capacitor_SMD:C_0805_2012Metric |  | CAP CER 3.3UF 10V X5R 0805 | 1276-2912-1-ND
C32 C33 | 2 | 2.2uF | Capacitor_SMD:C_0603_1608Metric | ~ | CAP CER 2.2UF 16V X5R 0603 | 1276-1040-1-ND
C34 | 1 | 100uF | Capacitor_SMD:C_1206_3216Metric | ~ | CAP TANT POLY 100UF 6.3V 1206 | 478-9563-1-ND
C5 | 1 | 0.01uF | Capacitor_SMD:C_0603_1608Metric |  | CAP CER 10000PF 50V X7R 0603 | 1276-1921-1-ND
C8 C9 C3 C4 C1 C6 C7 C28 C31 C30 C38 C39 C36 C37 C35 | 15 | 0.1uF | Capacitor_SMD:C_0603_1608Metric |  | CAP CER 0.1UF 25V X7R 0603 | 311-1341-1-ND
D1 | 1 | SMCJ45A | Diode_SMD:D_SMC |  | TVS DIODE 45V 72.7V DO214AB | SMCJ45ALFCT-ND
D13 | 1 | BLUE | LED_SMD:LED_0603_1608Metric_Pad1.05x0.95mm_HandSolder | ~ | LED BLUE CLEAR 0603 SMD | 732-4966-1-ND
D18 D17 D22 D20 | 4 | 1N4148W | Diode_SMD:D_SOD-323 |  | DIODE GEN PURP 75V 150MA SOD323 | 1N4148WXTPMSCT-ND
D2 D3 D19 | 3 | 3.3V | Diode_SMD:D_SOD-323 |  | TVS DIODE 3.3V SOD323 | 1727-4152-1-ND
D29 | 1 | D_TVS_x2_AAC | Package_TO_SOT_SMD:SOT-23 | ~ | TRANSIENT VOLTAGE SUPPRESSOR DIO | RESD1CANFHT116CT-ND
D4 | 1 | MMSZ5246B-7-F | Diode_SMD:D_SOD-123 |  | DIODE ZENER 16V 500MW SOD123 | MMSZ5246B-FDICT-ND
D5 D26 D27 D24 D23 D25 D9 | 7 | GREEN | LED_SMD:LED_0603_1608Metric_Pad1.05x0.95mm_HandSolder | ~ | LED GREEN CLEAR 0603 SMD | 732-4971-1-ND
D6 | 1 | MURS360T3G | Diode_SMD:D_SMC |  | DIODE GEN PURP 600V 3A SMC | MURS360T3GOSCT-ND
D7 D10 D11 D12 D15 D16 D21 | 7 | 5.6V | Diode_SMD:D_SOD-323 |  | Zener Diode 5.6V 400mW ±2% Surface Mount SOD-323 | MM3Z5V6BCT-ND
D8 | 1 | RED | LED_SMD:LED_0603_1608Metric_Pad1.05x0.95mm_HandSolder | ~ | LED RED CLEAR 0603 SMD | 732-4978-1-ND
F1 | 1 | 100mA | Fuse:Fuse_0805_2012Metric | ~ | PTC RESET FUSE 15V 50MA 0603 | 507-1816-1-ND
J10 | 1 | USB_B_Micro | bldc-BMS:USB_Micro-B_Amphenol_10103594-0001LF_Horizontal_circular | ~ | CONN RCPT USB2.0 MICRO B SMD R/A | 609-4050-1-ND
J2 | 1 | Conn_01x07 | Connector_JST:JST_PH_S7B-PH-K_1x07_P2.00mm_Horizontal | ~ | CONN HEADER R/A 7POS 2MM | 455-1724-ND
J3 | 1 | XT60_MALE | bldc-BMS:XT60PW-M20
J5 J1 | 2 | Conn_01x04 | Connector_JST:JST_PH_S4B-PH-K_1x04_P2.00mm_Horizontal |  | CONN HEADER R/A 4POS 2MM | 455-1721-ND
J6 | 1 | XT60_FEMALE | bldc-BMS:XT60PW-F20
J8 | 1 | Conn_01x06 | Connector_JST:JST_PH_S6B-PH-K_1x06_P2.00mm_Horizontal | ~ | CONN HEADER R/A 6POS 2MM | 455-1723-ND
J9 | 1 | Conn_01x02 | Connector_JST:JST_PH_S2B-PH-K_1x02_P2.00mm_Horizontal |  | CONN HEADER R/A 2POS 2MM | 455-1719-ND
JP1 JP2 | 2 | Jumper_NO | Jumper:SolderJumper-2_P1.3mm_Open_TrianglePad1.0x1.5mm | ~
JP3 | 1 | Jumper_NC_Small | Jumper:SolderJumper-2_P1.3mm_Bridged_RoundedPad1.0x1.5mm | ~
NT1 | 1 | Net-Tie | NetTie:NetTie-2_SMD_Pad0.5mm | ~
Q16 Q6 Q9 Q10 Q11 Q14 Q15 Q18 | 8 | Q_NMOS_GSD | Package_TO_SOT_SMD:SOT-23 |  | MOSFET N-CH 20V 0.63A SOT23-3 | DMN2004KDICT-ND
Q17 | 1 | ZXMP10A13FTA | Package_TO_SOT_SMD:SOT-23 |  | MOSFET P-CH 100V 0.6A SOT23-3 | ZXMP10A13FCT-ND
Q2 Q3 | 2 | CSD18531Q5A | Package_TO_SOT_SMD:TDSON-8-1 |  | MOSFET N-CH 60V 8SON 4.6mOHM | 296-30573-1-ND
Q5 | 1 | Q_PMOS | Package_TO_SOT_SMD:SOT-23-6 | ~ | MOSFET P-CH 60V 4A CPH6 | CPH6354-TL-WOSCT-ND
R11 R64 R65 R66 R67 R68 | 6 | 2k | Resistor_SMD:R_0603_1608Metric
R12 R13 R14 | 3 | 1k | Resistor_SMD:R_1206_3216Metric |  | RES SMD 1K OHM 5% 1/4W 1206 | 311-1.0KERCT-ND
R17 R20 R21 R22 R25 R26 | 6 | 33R | Resistor_SMD:R_2010_5025Metric |  | RES SMD 33 OHM 5% 3/4W 2010 | P33WCT-ND
R2 R4 R16 R1 R54 R56 | 6 | 100R | Resistor_SMD:R_0603_1608Metric
R27 R28 R31 R33 R34 R37 R38 R32 R39 | 9 | 1k 1% | Resistor_SMD:R_0603_1608Metric
R3 | 1 | 0.005R | Resistor_SMD:R_2512_6332Metric_Pad1.52x3.35mm_HandSolder | WSHM28185L000FEA | RES 0.005 OHM 1% 3W 2512 | CRE2512-FZ-R005E-3CT-ND
R40 R43 R44 R45 R48 R49 R51 R52 | 8 | 10k | Resistor_SMD:R_0603_1608Metric
R5 R10 | 2 | 1M | Resistor_SMD:R_0603_1608Metric
R50 R57 R55 R53 R63 R60 R70 R69 R71 R7 R8 | 11 | 100k | Resistor_SMD:R_0603_1608Metric
R58 R59 | 2 | 300k | Resistor_SMD:R_0603_1608Metric
R6 R15 R9 R73 R74 | 5 | 220R | Resistor_SMD:R_0603_1608Metric
R61 | 1 | 220k | Resistor_SMD:R_0603_1608Metric
R62 R75 | 2 | 1k | Resistor_SMD:R_0603_1608Metric
R76 R77 | 2 | 22R | Resistor_SMD:R_0603_1608Metric | ~
R78 | 1 | 120R | Resistor_SMD:R_0603_1608Metric | ~
SW1 SW2 | 2 | SW_Push | Button_Switch_SMD:SW_SPST_PTS810 |  | SWITCH TACTILE SPST-NO 50MA 32V | CKN10684CT-ND
TP1 | 1 | SCL | TestPoint:TestPoint_Pad_D1.5mm | ~
TP10 | 1 | BAT- | TestPoint:TestPoint_Pad_D1.5mm | ~
TP2 | 1 | SMBC | TestPoint:TestPoint_Pad_D1.5mm | ~
TP3 | 1 | REGOUT | TestPoint:TestPoint_Pad_D1.5mm | ~
TP4 | 1 | SDA | TestPoint:TestPoint_Pad_D1.5mm | ~
TP5 | 1 | SMBD | TestPoint:TestPoint_Pad_D1.5mm | ~
TP6 | 1 | BAT+ | TestPoint:TestPoint_Pad_D1.5mm | ~
TP7 | 1 | LOAD+ | TestPoint:TestPoint_Pad_D1.5mm | ~
TP8 | 1 | 3.3V | TestPoint:TestPoint_Pad_D1.5mm | ~
TP9 | 1 | 5V | TestPoint:TestPoint_Pad_D1.5mm | ~
U1 | 1 | bq76200 | Package_SO:TSSOP-16_4.4x5mm_P0.65mm |  | HIGH-SIDE N-CH FET DRVR 16TSSOP | 296-43273-1-ND
U2 | 1 | bq76930 | Package_SO:TSSOP-30_4.4x7.8mm_P0.5mm |  | IC BATT MGMT LI-ION AFE 30TSSOP | 296-39961-1-ND
U3 | 1 | BQ78350-R1 | Package_SO:TSSOP-30_4.4x7.8mm_P0.5mm |  | IC BATTERY MGMT CTRLR 30TSSOP | 296-44315-1-ND
U4 | 1 | MIC5219-3.3 | bldc-BMS:SOT-23-5 | http://www.advanced-monolithic.com/pdf/ds1117.pdf | IC REG LINEAR 3.3V 500MA SOT23-5 | 576-1281-1-ND
U5 | 1 | MIC5239-5.0 | Package_TO_SOT_SMD:SOT-223 | http://www.st.com/content/ccc/resource/technical/document/datasheet/15/55/e5/aa/23/5b/43/fd/CD00000446.pdf/files/CD00000446.pdf/jcr:content/translations/en.CD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 | IC REG LINEAR 5V 500MA SOT223 | 576-2397-1-ND
U6 | 1 | TJA1042T-3 | Package_SO:SOIC-8_3.9x4.9mm_P1.27mm | http://www.nxp.com/documents/data_sheet/TJA1042.pdf | IC CAN TRANSEIVER HS 8SOIC | 568-8678-1-ND
U7 | 1 | STM32F072C8 | Package_QFP:LQFP-48_7x7mm_P0.5mm |  | IC MCU 32BIT 64KB FLASH 48LQFP | 497-17359-1-ND
Y1 | 1 | 8MHz | Crystal:Crystal_SMD_5032-4Pin_5.0x3.2mm |  | CRYSTAL 8.0000MHZ 10PF SMD | 535-9721-1-ND

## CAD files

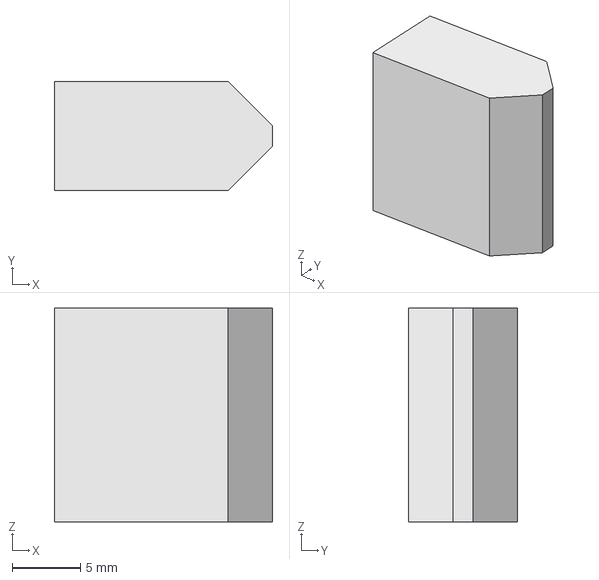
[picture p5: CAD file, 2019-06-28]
datasheets/XT90_female.fcstd
16.0 x 8.00 x 15.7 mm

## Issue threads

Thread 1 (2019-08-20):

Hello Thank you for sharing, why can't I open your project with KiCad5.14?

SecturityException, 2019-08-20:
Hello Thank you for sharing, why can't I open your project with KiCad5.14?

mpater, 2019-08-22:
Hello. Are you having any specific errors?
I believe KiCad should be able to detect and open/import/convert a KiCad 4 to KiCad 5 project. I'll update and push the changes in a couple of days.

SecturityException, 2019-08-22:
> Hello. Are you having any specific errors?
> I believe KiCad should be able to detect and open/import/convert a KiCad 4 to KiCad 5 project. I'll update and push the changes in a couple of days.

SecturityException, 2019-08-22:
I can only open "bldc-BMS.sch" but cannot open other schematics

mpater, 2019-08-23:
Pushed updates, lots of content updated. Has been saved in 5.1.4 as well. Give it another go.

SecturityException, 2019-08-24:
I will try again, thank you for your help.

Closed 2019-08-24.

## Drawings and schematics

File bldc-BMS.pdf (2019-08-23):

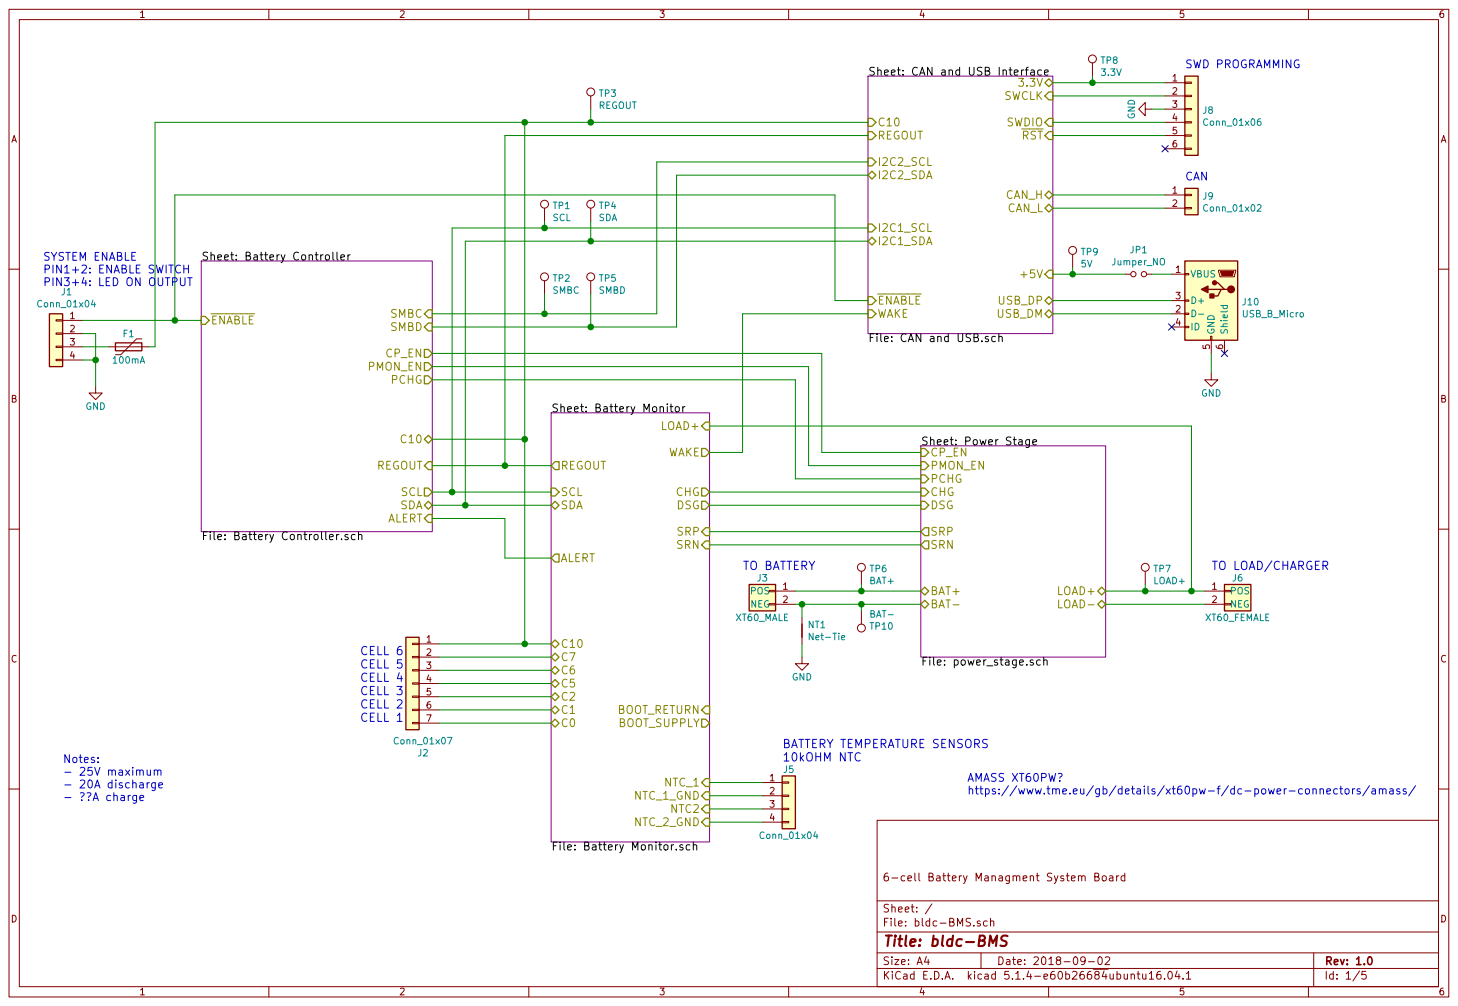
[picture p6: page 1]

Sheet: CAN and USB Interface
3.3V WAKE

File: CAN and USB.sch

File: Battery Controller.sch

AMASS XT60PW?
https://www.tme.eu/gb/details/xt60pw-f/dc-power-connectors/amass/

File: Battery Monitor.sch

File: bldc-BMS.sch Sheet: / 6-cell Battery Managment System Board

Id: 1/5 Title: bldc-BMS

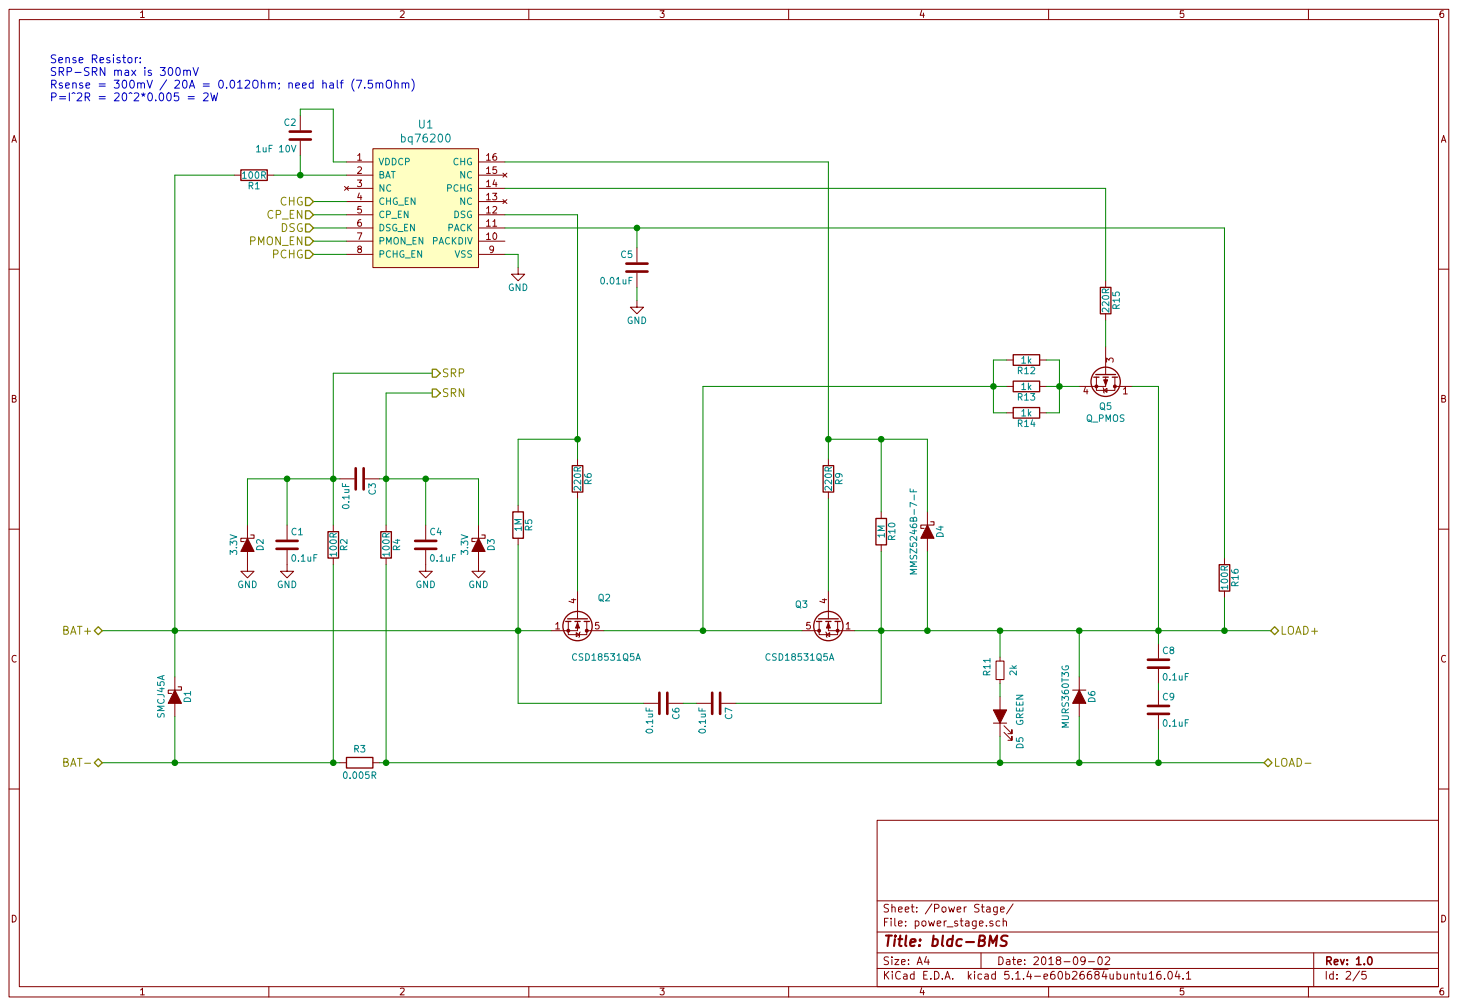
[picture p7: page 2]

Sense Resistor:
SRP-SRN max is 300mV
Rsense = 300mV / 20A = 0.012Ohm; need half (7.5mOhm) P=I^2R = 20^2*0.005 = 2W

File: power_stage.sch
Id: 2/5 Title: bldc-BMS

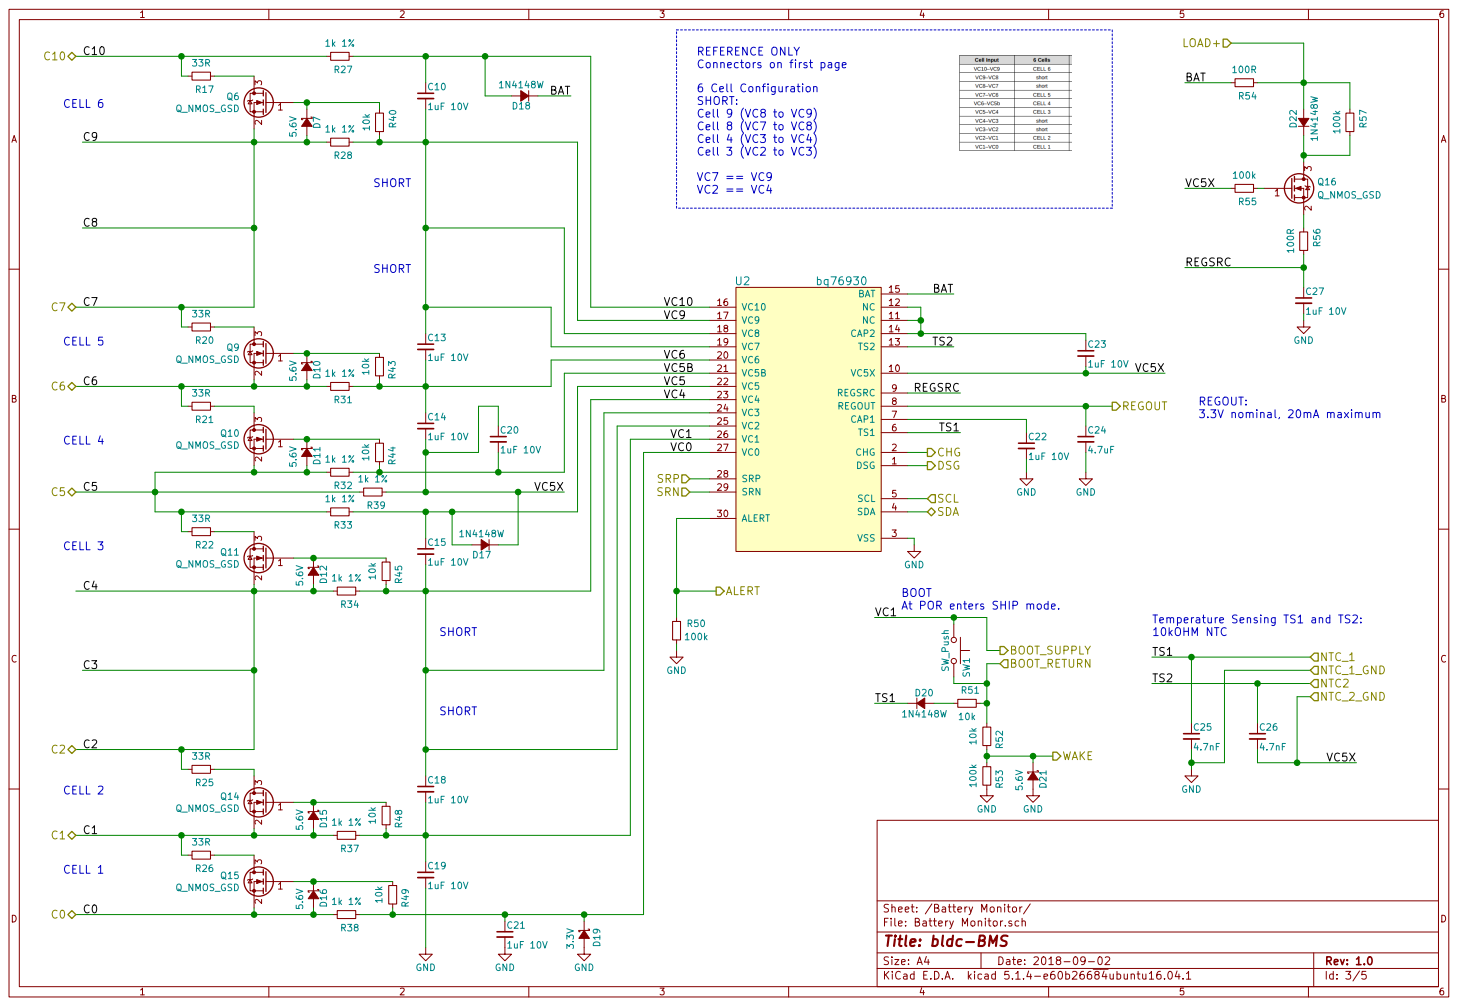
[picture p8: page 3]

REFERENCE ONLY
Connectors on first page
6 Cell Configuration
SHORT:
Cell 9 (VC8 to VC9)
Cell 8 (VC7 to VC8)
Cell 4 (VC3 to VC4)
Cell 3 (VC2 to VC3)

BOOT
At POR enters SHIP mode.

File: Battery Monitor.sch
Id: 3/5 Title: bldc-BMS

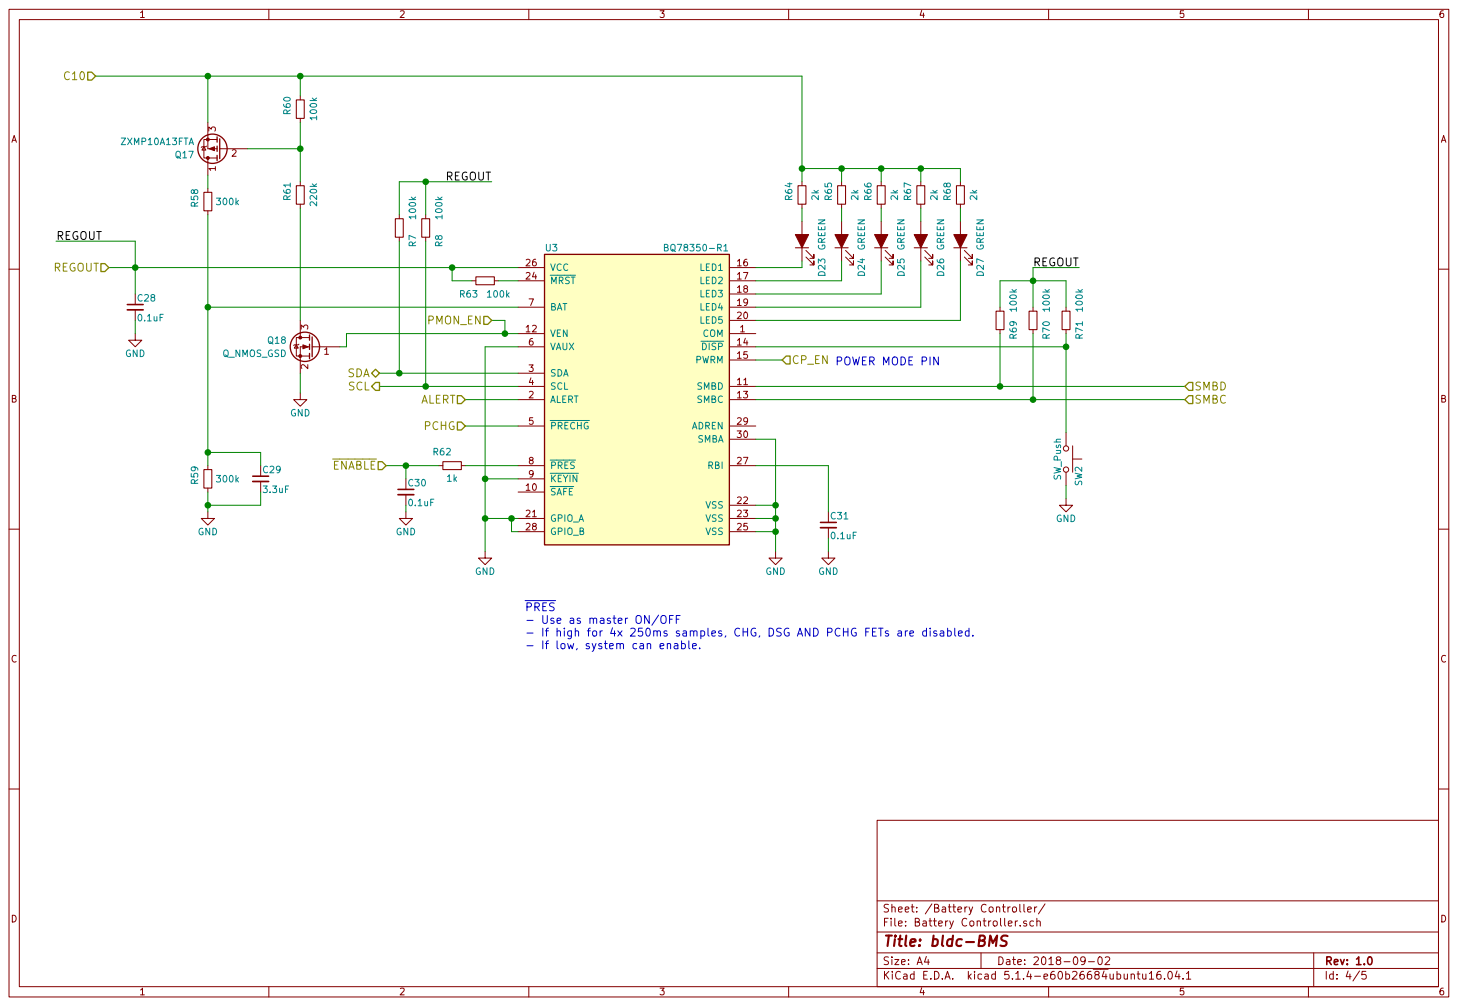
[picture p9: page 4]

PRES
- Use as master ON/OFF
- If high for 4x 250ms samples, CHG, DSG AND PCHG FETs are disabled.
- If low, system can enable.

File: Battery Controller.sch
Id: 4/5 Title: bldc-BMS

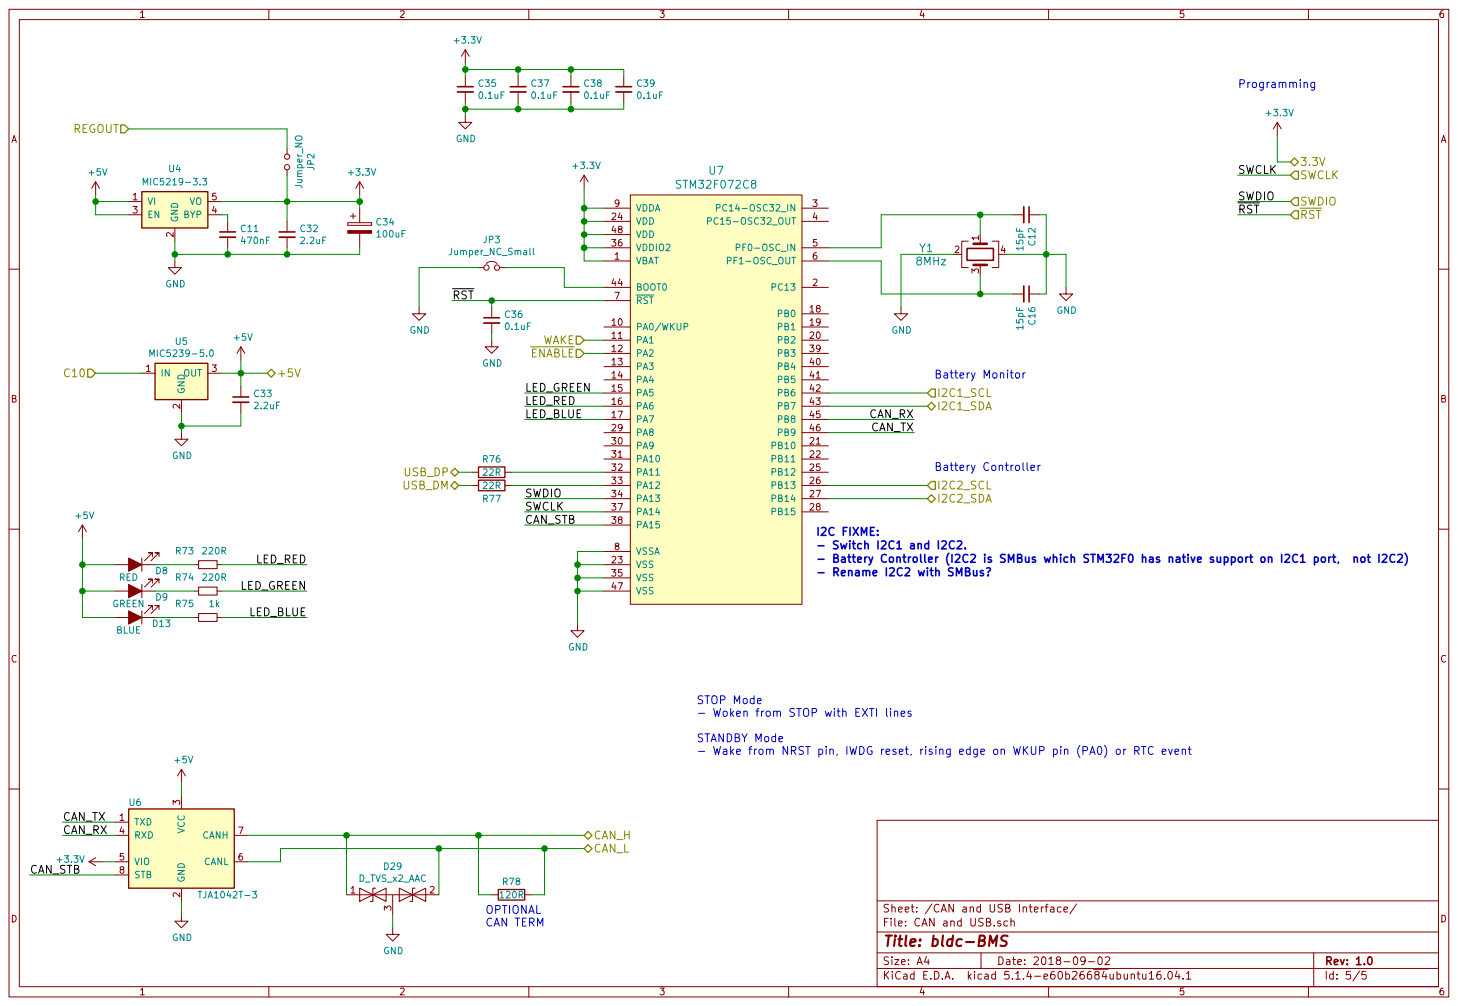
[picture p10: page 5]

File: CAN and USB.sch Sheet: /CAN and USB Interface/C16 15pF

LED_RED
LED_BLUE

I2C FIXME:
- Switch I2C1 and I2C2.
- Battery Controller (I2C2 is SMBus which STM32F0 has native support on I2C1 port, not I2C2)
- Rename I2C2 with SMBus?

STOP Mode
- Woken from STOP with EXTI lines

STANDBY Mode
- Wake from NRST pin, IWDG reset, rising edge on WKUP pin (PA0) or RTC event

3 RXD 4 VIO 5 CANL 6 CANH 7 STB 8 U6 TJA1042T-3

Id: 5/5 Title: bldc-BMS

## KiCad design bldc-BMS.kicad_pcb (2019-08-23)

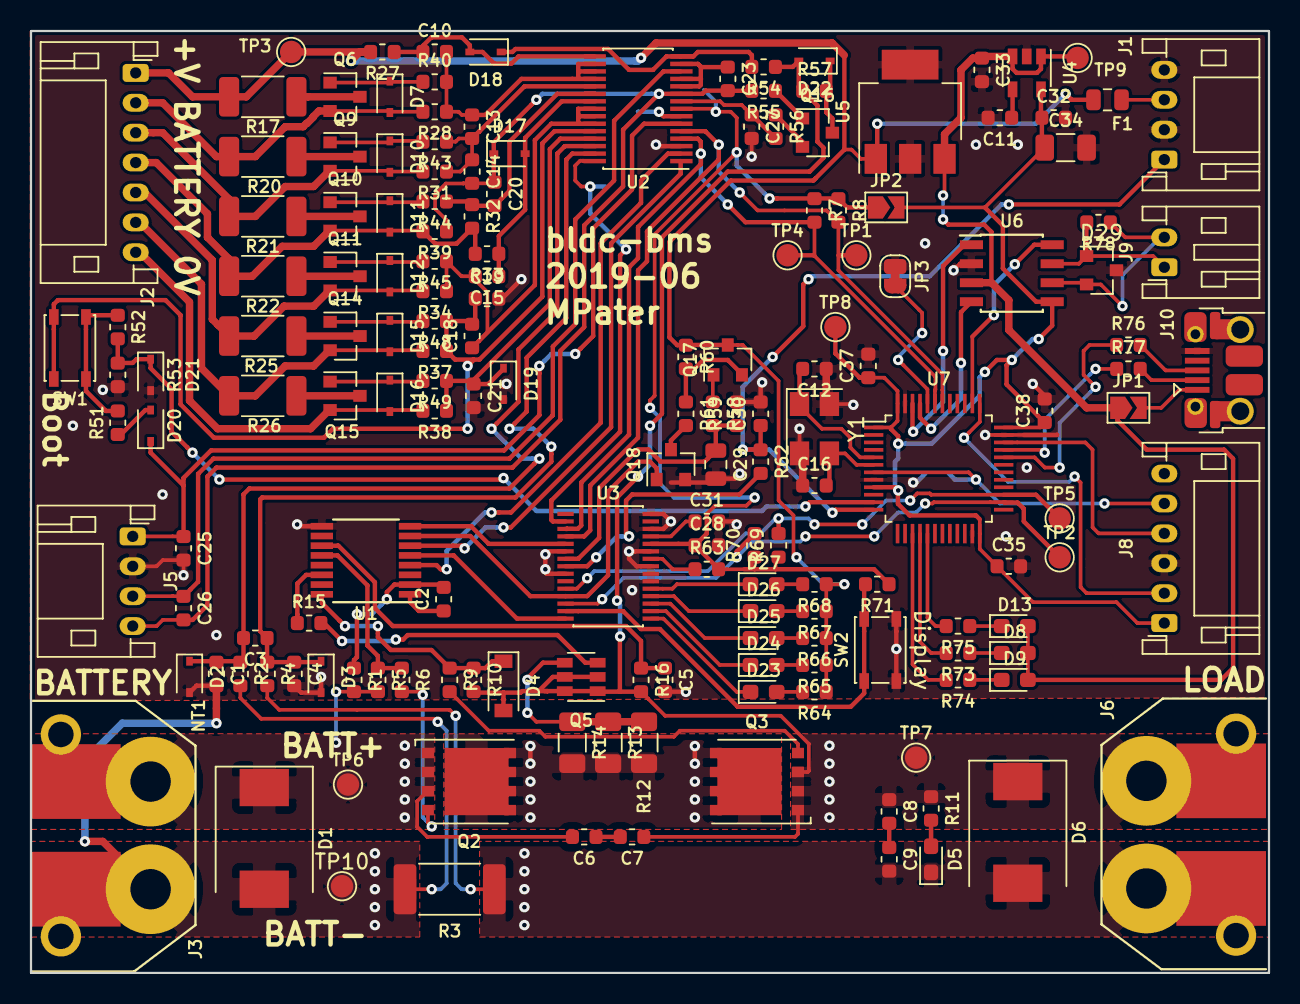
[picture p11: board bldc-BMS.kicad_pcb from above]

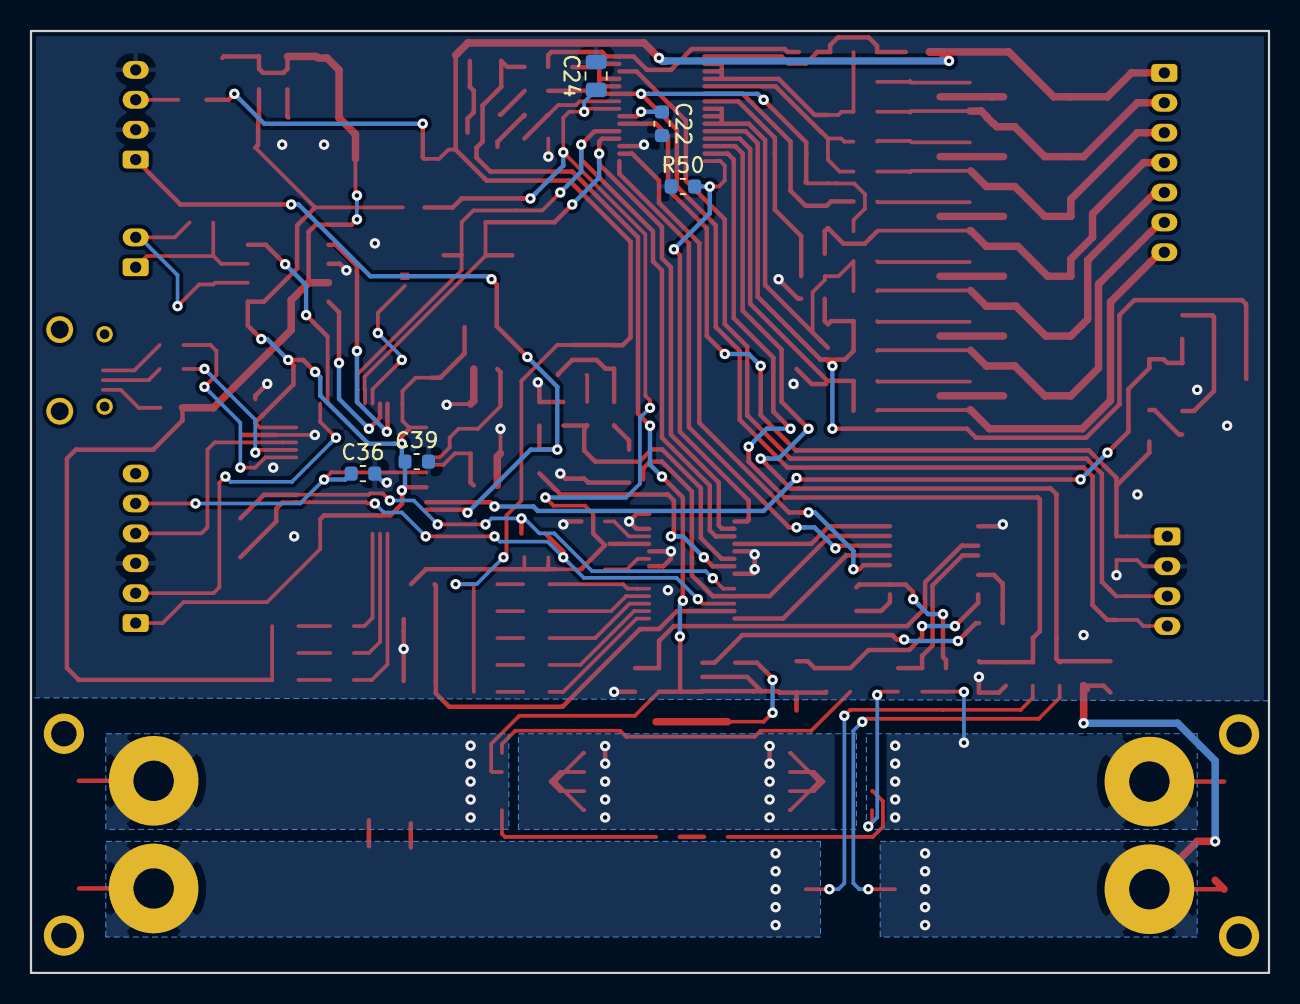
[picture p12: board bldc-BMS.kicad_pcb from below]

Board: 2 copper layers, 82.8 x 63.0 mm, 175 parts (5 on the bottom side), 117 nets.

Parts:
C1, C3, C4, C6, C7, C8, C9, C28, C30, C31, C35, C36, C37, C38, C39: 0.1uF; C_0603_1608Metric
C2, C10, C13, C14, C15, C18, C19, C20, C21, C22, C23, C27: 1uF 10V; C_0603_1608Metric
C5: 0.01uF; C_0603_1608Metric
C11: 470nF; C_0603_1608Metric
C12, C16: 15pF; C_0603_1608Metric
C24: 4.7uF; C_0805_2012Metric
C25, C26: 4.7nF; C_0603_1608Metric
C29: 3.3uF; C_0805_2012Metric
C32, C33: 2.2uF; C_0603_1608Metric
C34: 100uF; C_1206_3216Metric
D1: SMCJ45A; D_SMC
D2, D3, D19: 3.3V; D_SOD-323
D4: MMSZ5246B-7-F; D_SOD-123
D5, D9, D23, D24, D25, D26, D27: GREEN; LED_0603_1608Metric_Pad1.05x0.95mm_HandSolder
D6: MURS360T3G; D_SMC
D7, D10, D11, D12, D15, D16, D21: 5.6V; D_SOD-323
D8: RED; LED_0603_1608Metric_Pad1.05x0.95mm_HandSolder
D13: BLUE; LED_0603_1608Metric_Pad1.05x0.95mm_HandSolder
D17, D18, D20, D22: 1N4148W; D_SOD-323
D29: D_TVS_x2_AAC; D_SOT-23_TVS
F1: 100mA; Fuse_0805_2012Metric
J1, J5: Conn_01x04; JST_PH_S4B-PH-K_1x04_P2.00mm_Horizontal
J2: Conn_01x07; JST_PH_S7B-PH-K_1x07_P2.00mm_Horizontal
J3: XT60_MALE; XT60PW-M20
J6: XT60_FEMALE; XT60PW-F20
J8: Conn_01x06; JST_PH_S6B-PH-K_1x06_P2.00mm_Horizontal
J9: Conn_01x02; JST_PH_S2B-PH-K_1x02_P2.00mm_Horizontal
J10: USB_B_Micro; USB_Micro-B_Amphenol_10103594-0001LF_Horizontal_circular
JP1, JP2: Jumper_NO; SolderJumper-2_P1.3mm_Open_TrianglePad1.0x1.5mm
JP3: Jumper_NC_Small; SolderJumper-2_P1.3mm_Bridged_RoundedPad1.0x1.5mm
NT1: Net-Tie; NetTie-2_SMD_Pad0.5mm
Q2, Q3: CSD18531Q5A; TDSON-8-1
Q5: Q_PMOS; SOT-23-6
Q6, Q9, Q10, Q11, Q14, Q15, Q16, Q18: Q_NMOS_GSD; SOT-23
Q17: ZXMP10A13FTA; SOT-23
R1, R2, R4, R16, R54, R56: 100R; R_0603_1608Metric
R3: 0.005R; R_2512_6332Metric_Pad1.52x3.35mm_HandSolder
R5, R10: 1M; R_0603_1608Metric
R6, R9, R15, R73, R74: 220R; R_0603_1608Metric
R7, R8, R50, R53, R55, R57, R60, R63, R69, R70, R71: 100k; R_0603_1608Metric
R11, R64, R65, R66, R67, R68: 2k; R_0603_1608Metric
R12, R13, R14: 1k; R_1206_3216Metric
R17, R20, R21, R22, R25, R26: 33R; R_2010_5025Metric
R27, R28, R31, R32, R33, R34, R37, R38, R39: 1k 1%; R_0603_1608Metric
R40, R43, R44, R45, R48, R49, R51, R52: 10k; R_0603_1608Metric
R58, R59: 300k; R_0603_1608Metric
R61: 220k; R_0603_1608Metric
R62, R75: 1k; R_0603_1608Metric
R76, R77: 22R; R_0603_1608Metric
R78: 120R; R_0603_1608Metric
SW1, SW2: SW_Push; SW_SPST_PTS810
TP1: SCL; TestPoint_Pad_D1.5mm
TP2: SMBC; TestPoint_Pad_D1.5mm
TP3: REGOUT; TestPoint_Pad_D1.5mm
TP4: SDA; TestPoint_Pad_D1.5mm
TP5: SMBD; TestPoint_Pad_D1.5mm
TP6: BAT+; TestPoint_Pad_D1.5mm
TP7: LOAD+; TestPoint_Pad_D1.5mm
TP8: 3.3V; TestPoint_Pad_D1.5mm
TP9: 5V; TestPoint_Pad_D1.5mm
TP10: BAT-; TestPoint_Pad_D1.5mm
U1: bq76200; TSSOP-16_4.4x5mm_P0.65mm
U2: bq76930; TSSOP-30_4.4x7.8mm_P0.5mm
U3: BQ78350-R1; TSSOP-30_4.4x7.8mm_P0.5mm
U4: MIC5219-3.3; SOT-23-5
U5: MIC5239-5.0; SOT-223
U6: TJA1042T-3; SOIC-8_3.9x4.9mm_P1.27mm
U7: STM32F072C8; LQFP-48_7x7mm_P0.5mm
Y1: 8MHz; Crystal_SMD_5032-4Pin_5.0x3.2mm

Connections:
+3V3: C32.1, C34.1, C35.1, C37.1, C38.1, C39.1, J8.1, JP2.2, TP8.1, U4.5, U6.5, U7.1, U7.9, U7.24, U7.36, U7.48
+5V: C33.1, D8.2, D9.2, D13.2, JP1.1, TP9.1, U4.1, U4.3, U5.3, U6.3
/Battery Controller/ALERT: R50.2, U2.30, U3.2
/Battery Controller/C10: F1.1, J2.1, Q17.3, R17.2, R27.2, R60.1, R64.1, R65.1, R66.1, R67.1, R68.1, TP3.1, U5.1
/Battery Controller/CP_EN: U1.5, U3.15
/Battery Controller/PCHG: U1.8, U3.5
/Battery Controller/PMON_EN: Q18.1, U1.7, U3.12
/Battery Controller/REGOUT: C24.1, C28.1, JP2.1, R7.1, R8.1, R63.2, R69.1, R70.1, R71.1, U2.8, U3.26
/Battery Controller/~ENABLE: C30.1, J1.1, R62.1, U7.12
/Battery Monitor/BAT: D18.1, R54.2, U2.15
/Battery Monitor/BOOT_RETURN: R51.1, R52.2, SW1.2
/Battery Monitor/BOOT_SUPPLY: C18.2, C19.1, R37.1, R48.1, SW1.1, U2.26
/Battery Monitor/C0: D16.2, J2.7, Q15.2, R38.2
/Battery Monitor/C1: D15.2, J2.6, Q14.2, R26.2, R37.2
/Battery Monitor/C2: D12.2, J2.5, Q11.2, R25.2, R34.2
/Battery Monitor/C5: D11.2, J2.4, Q10.2, R22.2, R32.2, R33.2, R39.2
/Battery Monitor/C6: D10.2, J2.3, Q9.2, R21.2, R31.2
/Battery Monitor/C7: D7.2, J2.2, Q6.2, R20.2, R28.2
/Battery Monitor/CHG: U1.4, U2.2
/Battery Monitor/DSG: U1.6, U2.1
/Battery Monitor/LOAD+: C7.1, C8.1, D4.2, D6.1, D22.2, J6.1, Q3.1, Q3.2, Q3.3, Q5.1, Q5.2, Q5.5, Q5.6, R10.2, R11.1, R16.2, R54.1, R57.1, TP7.1
/Battery Monitor/NTC2: C26.1, J5.3, U2.13
/Battery Monitor/NTC_1: C25.1, D20.1, J5.1, U2.6
/Battery Monitor/NTC_2_GND: C14.2, C20.1, C23.2, C26.2, D17.1, J5.4, R39.1, R55.2, U2.10
/Battery Monitor/REGSRC: C27.1, R56.2, U2.9
/Battery Monitor/SRN: C3.1, C4.1, D3.1, R4.1, U2.29
/Battery Monitor/SRP: C1.1, C3.2, D2.1, R2.1, U2.28
/Battery Monitor/VC0: C21.1, D19.1, R38.1, R49.1, U2.27
/Battery Monitor/VC4: C15.2, C18.1, R34.1, R45.1, U2.23, U2.24, U2.25
/Battery Monitor/VC5: C15.1, D17.2, R33.1, U2.22
/Battery Monitor/VC5B: C20.2, R32.1, R44.1, U2.21
/Battery Monitor/VC6: C13.2, C14.1, R31.1, R43.1, U2.20
/Battery Monitor/VC9: C10.2, C13.1, R28.1, R40.2, U2.17, U2.18, U2.19
/Battery Monitor/VC10: C10.1, D18.2, R27.1, U2.16
/Battery Monitor/WAKE: D21.1, R52.1, R53.2, U7.11
/CAN and USB Interface/CAN_H: D29.1, J9.1, R78.2, U6.7
/CAN and USB Interface/CAN_L: D29.2, J9.2, R78.1, U6.6
/CAN and USB Interface/CAN_RX: U6.4, U7.45
/CAN and USB Interface/CAN_STB: U6.8, U7.38
/CAN and USB Interface/CAN_TX: U6.1, U7.46
/CAN and USB Interface/I2C1_SCL: R8.2, TP1.1, U2.5, U3.4, U7.42
/CAN and USB Interface/I2C1_SDA: R7.2, TP4.1, U2.4, U3.3, U7.43
/CAN and USB Interface/I2C2_SCL: R70.2, TP2.1, U3.13, U7.26
/CAN and USB Interface/I2C2_SDA: R69.2, TP5.1, U3.11, U7.27
/CAN and USB Interface/LED_BLUE: R75.2, U7.17
/CAN and USB Interface/LED_GREEN: R74.2, U7.15
/CAN and USB Interface/LED_RED: R73.2, U7.16
/CAN and USB Interface/SWCLK: J8.2, U7.37
/CAN and USB Interface/SWDIO: J8.4, U7.34
/CAN and USB Interface/USB_DM: J10.2, R77.2
/CAN and USB Interface/USB_DP: J10.3, R76.2
/CAN and USB Interface/~RST: C36.1, J8.5, U7.7
/Power Stage/BAT+: C6.2, D1.1, J3.1, Q2.1, Q2.2, Q2.3, R1.2, R5.2, TP6.1
/Power Stage/BAT-: D1.2, J3.2, NT1.1, R2.2, R3.1, TP10.1
/Power Stage/LOAD-: C9.2, D5.1, D6.2, J6.2, R3.2, R4.2
GND: C1.2, C4.2, C5.2, C11.2, C12.1, C16.1, C19.2, C21.2, C22.2, C24.2, C25.2, C27.2, C28.2, C29.2, C30.2, C31.2, C32.2, C33.2, C34.2, C35.2, C36.2, C37.2, C38.2, C39.2, D2.2, D3.2, D19.2, D21.2, D29.3, J1.2, J1.4, J5.2, J8.3, J10.5, JP3.1, NT1.2, Q18.2, R50.1, R53.1, R59.2, SW2.2, U1.9, U2.3, U3.6, U3.9, U3.21, U3.22, U3.23, U3.25, U3.28, U3.30, U4.2, U5.2, U6.2, U7.8, U7.23, U7.35, U7.47, Y1.2, Y1.4
unnamed: C2.1, U1.1
unnamed: C2.2, R1.1, U1.2
unnamed: C5.1, R16.1, U1.11
unnamed: C6.1, C7.2
unnamed: C8.2, C9.1
unnamed: C11.1, U4.4
unnamed: C12.2, U7.5, Y1.1
unnamed: C16.2, U7.6, Y1.3
unnamed: C22.1, U2.7
unnamed: C23.1, U2.11, U2.12, U2.14
unnamed: C29.1, R58.2, R59.1, U3.7
unnamed: C31.1, U3.27
unnamed: D4.1, R9.1, R10.1, U1.16
unnamed: D5.2, R11.2
unnamed: D7.1, Q6.1, R40.1
unnamed: D8.1, R73.1
unnamed: D9.1, R74.1
unnamed: D10.1, Q9.1, R43.2
unnamed: D11.1, Q10.1, R44.2
unnamed: D12.1, Q11.1, R45.2
unnamed: D13.1, R75.1
unnamed: D15.1, Q14.1, R48.2
unnamed: D16.1, Q15.1, R49.2
unnamed: D20.2, R51.2
unnamed: D22.1, Q16.3, R57.2
unnamed: D23.1, U3.16
unnamed: D23.2, R64.2
unnamed: D24.1, U3.17
unnamed: D24.2, R65.2
unnamed: D25.1, U3.18
unnamed: D25.2, R66.2
unnamed: D26.1, U3.19
unnamed: D26.2, R67.2
unnamed: D27.1, U3.20
unnamed: D27.2, R68.2
unnamed: F1.2, J1.3
unnamed: J10.1, JP1.2
unnamed: JP3.2, U7.44
unnamed: Q2.4, R6.2
unnamed: Q2.5, Q3.5, R12.2, R13.2, R14.2
unnamed: Q3.4, R9.2
unnamed: Q5.3, R15.2
unnamed: Q5.4, R12.1, R13.1, R14.1
unnamed: Q6.3, R17.1
unnamed: Q9.3, R20.1
unnamed: Q10.3, R21.1
unnamed: Q11.3, R22.1
unnamed: Q14.3, R25.1
unnamed: Q15.3, R26.1
unnamed: Q16.1, R55.1
unnamed: Q16.2, R56.1
unnamed: Q17.1, R58.1
unnamed: Q17.2, R60.2, R61.1
unnamed: Q18.3, R61.2
unnamed: R5.1, R6.1, U1.12
unnamed: R15.1, U1.14
unnamed: R62.2, U3.8
unnamed: R63.1, U3.24
unnamed: R71.2, SW2.1, U3.14
unnamed: R76.1, U7.32
unnamed: R77.1, U7.33

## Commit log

2018-06-24 readme formatting corrections and adding schematic PDF
2018-09-02 Updated top-level connections and added MCU
    [Battery Controller.sch, Battery Monitor-2018-07-29-19-59-33.sch, Battery Monitor.sch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]
2019-06-28 Good-enough for first PCB attempt.
    [Battery Controller.sch, Battery Monitor.sch, CAN and USB.sch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]
2019-08-23 first PCB spin for testing
    [Battery Monitor.sch, CAN and USB.sch, bldc-BMS.kicad_pcb]
2019-08-23 added test PCB note
2019-08-23 added schematic pdf
